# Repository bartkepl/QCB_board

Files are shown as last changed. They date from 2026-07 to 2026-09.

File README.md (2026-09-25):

# QCB (Quad Card Backplane)

Quad Card Backplane for 3U eurocards. Splits USB 2.0 and 10/100M Ethernet (plus RS485 and an ID EEPROM) out to 4 eurocards.

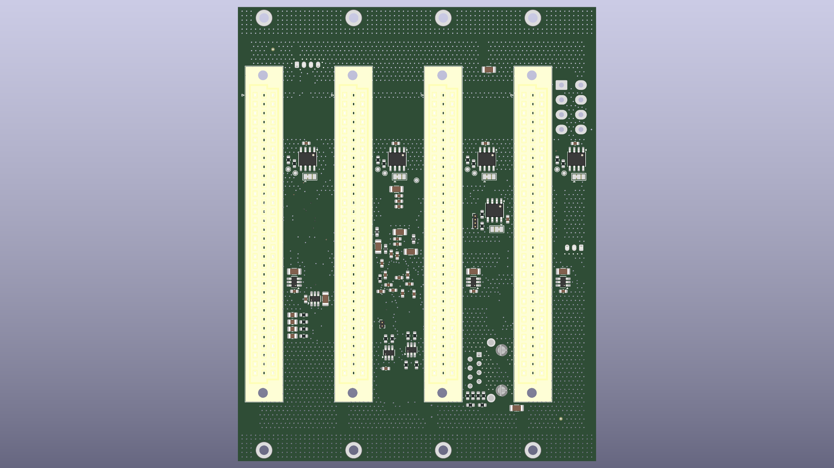
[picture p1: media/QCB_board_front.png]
Quad Card Backplane board


<p align="center">
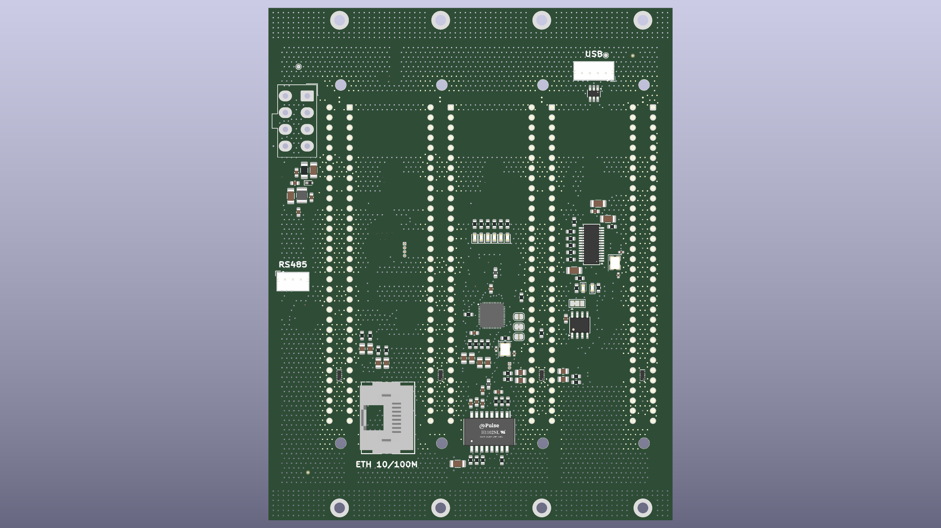
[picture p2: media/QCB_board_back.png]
QCB board back
  
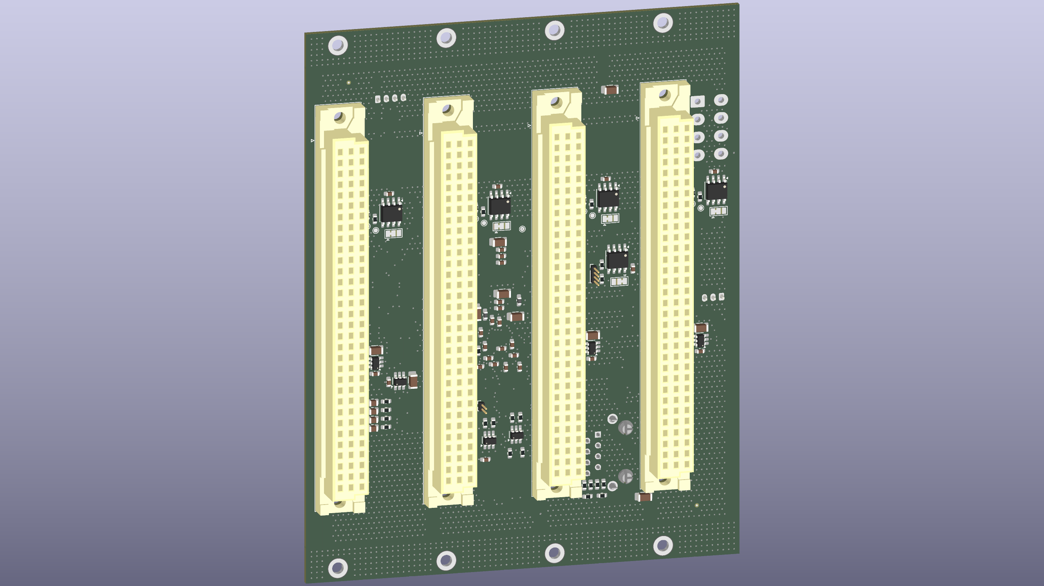
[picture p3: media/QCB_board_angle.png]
QCB board angle
  
</p>

---

## Status: ready for prototype order

- Schematic and PCB routing are done (rev 0.1), production files generated.
- A full design review (schematic + PCB + EMC + SPICE) was completed on 2026-08-03 and re-checked since; see [Documentation](#documentation) below.
- Fiducials added (2 per side, hand assembly), Y2 load caps C41/C42 now included in the BOM, datasheets for IP175G, FE1.1s and UT8413A in [doc/datasheet/](doc/datasheet/).

Production outputs: [schematic PDF](prod/sch/QCB_board.pdf) · [PCB PDF](prod/pcb/QCB_board.pdf) · [interactive BOM](prod/ibom/QCB_board_ibom.html) · [gerbers](prod/QCB_board.zip)

---

## Architecture

The board is a backplane hub card built around two switching ICs, fanned out to 4 identical eurocard channels:

- **U1 (FE1.1s)** — 4-port USB 2.0 Hi-Speed hub, one port per channel.
- **IC1 (IP175G)** — 5-port 10/100 Ethernet switch. One port is broken out to an RJ45 (J3) via magnetics (H1102NL); the other 4 go to the channels.
- **4× channel (`con1.kicad_sch`, reused as CON1–CON4)** — each with its own USB D+/D-, Ethernet TX/RX pairs, RS485±, ESD protection, and an identification EEPROM (M24C02) on its own I2C bus.
- **`pwr.kicad_sch`** — power input (Molex Mini-Fit connector J6), polyfuse, ferrite bead, ESD protection. No on-board regulator — +3.3V/+5V/+12V are supplied by the backplane.
- Channels land on 4 backplane connectors (DIN41612 2×32, J7–J10).

4-layer PCB (F.Cu / In1.Cu / In2.Cu / B.Cu), 101.6 × 128.7 mm.

## Features

- 10/100 Ethernet switch with an external RJ45 port
- USB 2.0 Hi-Speed 4-port hub
- Per-channel RS485 and identification EEPROM
- 4× 3U 6TE eurocard, IEEE 1101.1-1998 format (128 × 30.1 mm)
- Powered entirely from the backplane (no on-board regulator)

## Repository structure

```
pcb/        KiCad project (schematic, PCB, jobsets, 3D packages, datasheets cache)
doc/        Design review report, TODO list and component datasheets (tracked, human-readable)
media/      Renders/photos used in this README
prod/       Generated production outputs (gerbers/zip, BOM, schematic & PCB PDFs)
analysis/   Raw output of automated design-review tooling (gitignored, regenerable)
```

## Documentation

- [doc/DESIGN_REVIEW_2026-08-03.md](doc/DESIGN_REVIEW_2026-08-03.md) — full schematic/PCB/EMC/SPICE design review
- [doc/TODO.md](doc/TODO.md) — outstanding items before the board can be ordered

## License and Contribution

[MIT License](/LICENSE)

Open to contributions in both software and hardware!

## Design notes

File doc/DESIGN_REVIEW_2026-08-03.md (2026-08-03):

# Design Review — QuadCardBackplane_board (QCB), rev 0.1

Data przeglądu: 2026-08-03
Zakres: `pcb/QCB_board.kicad_sch` (+ arkusze `con1`, `eth_switch`, `usb_switch`, `pwr`) oraz `pcb/QCB_board.kicad_pcb`
Narzędzia: kicad-happy `kicad` (schematic/pcb/cross-analysis), `emc`, `spice` (ngspice), `analyze_thermal`, natywny `kicad-cli sch erc` / `kicad-cli pcb drc` (KiCad 10.0.4)

---

## 1. Co to za płytka

4-warstwowa karta backplane (F.Cu / In1.Cu / In2.Cu / B.Cu, grubość 1.586 mm), 101.6 × 128.7 mm, 216 komponentów. Funkcjonalnie:

- **U1 (FE1.1s)** — 4-portowy hub USB 2.0 Hi-Speed (480 Mb/s), rozprowadza D+/D− do 4 kanałów backplane (CON1–CON4).
- **IC1 (IP175G)** — 5-portowy switch Ethernet 10/100. Port 5 wyprowadzony na złącze RJ45 (J3, magnetyka H1102NL), porty 1–4 idą do kanałów backplane.
- **4× kanał (con1.kicad_sch reużyty jako CON1…CON4)** — każdy z własną parą USB D+/D−, parą Ethernet (CON_TX±/CON_RX±), RS485±, EEPROM identyfikacyjnym M24C02 na wspólnej magistrali I2C, ESD (USBLC6-2SC6, UT8413A) — wyprowadzone na złącza backplane DIN41612 2×32 (J7/J8/J9/J10).
- **pwr.kicad_sch** — wejście zasilania (złącze Molex Mini-Fit J6), bezpiecznik polimerowy F1, ferryt/dławik L1, ESD (D10). **Brak regulatora napięcia na płycie** — +3.3 V (i pozostałe szyny) pochodzą z backplane'u.

Zgodność schematyk↔PCB: **216 komponentów w schemacie = 216 footprintów na PCB** (dokładna zgodność). Liczba sieci: 237 (schematic) vs 263 (PCB) — różnica wynika z metodyki liczenia (PCB dolicza `unconnected-(...)` na niewykorzystanych pinach złączy DIN41612), nie jest błędem.

## 2. Co zostało uruchomione / czego brakowało

| Krok | Status |
|---|---|
| `analyze_schematic.py` | ✅ |
| `analyze_pcb.py --full --proximity` | ✅ |
| `cross_analysis.py` | ✅ (33 findings) |
| `analyze_emc.py` | ✅ (115 findings, 9 kategorii) |
| `kicad-cli sch erc` / `pcb drc` (natywny silnik KiCad 10.0.4) | ✅ — uruchomiony dodatkowo, poza standardowym workflow skilla, bo `D:\KiCad\10.0\bin\kicad-cli.exe` był dostępny |
| SPICE (ngspice) | ✅ — ngspice nie był w PATH, znaleziony pod `D:\Spice64\bin\ngspice.exe` (podałeś ścieżkę), użyty przez `NGSPICE_PATH`. 22 symulacje, 21 pass / 1 warn |
| Thermal | ✅ — 0 findings (na płycie nie ma zidentyfikowanych komponentów mocy typu regulator/driver z istotną dyssypacją — spójne z brakiem regulatora na tej karcie) |
| Sync datasheetów (DigiKey) | ❌ brak `DIGIKEY_CLIENT_ID`/`SECRET` w środowisku |
| Sync datasheetów (LCSC, bez klucza) | ⚠️ częściowy — tylko **1/10** komponentów z MPN miało pobieralny datasheet (H1102NL). Reszta (kondensatory GRM…, IP175G, USBLC6-2SC6 itd.) nie została znaleziona w LCSC/alt. źródłach automatycznie |
| Weryfikacja krytycznych pinów wobec prawdziwego datasheetu | ✅ ręcznie via WebSearch/WebFetch dla FE1.1s (Terminus Technology, Rev 1.0) — patrz sekcja 4 |
| Lifecycle audit (obsolescence) | ⛔ nie uruchomiony — pokrycie MPN w BOM to tylko 33% (13/39 unikalnych linii), audyt miałby sens dopiero po uzupełnieniu MPN |
| Gerber analyzer | ⛔ nie uruchomiony — w projekcie nie ma jeszcze wyeksportowanych gerberów |

**Uwaga o poziomie zaufania**: przy MPN pokryciu 33% i praktycznie zerowym pokryciu datasheetami, większość poniższych ustaleń to **weryfikacja spójności** (schemat ↔ PCB ↔ symbol biblioteczny), nie pełna weryfikacja wobec danych producenta — poza miejscami, gdzie jawnie cytuję konkretny datasheet (FE1.1s).

---

## 3. NAJWAŻNIEJSZE — realne błędy potwierdzone na surowych danych

### 3.1 ~~🔴 Kolizja adresów I2C~~ — WYCOFANE (2026-08-04)

> **Korekta**: to nie jest błąd. Autor potwierdził, że U6/U8/U10/U12 siedzą na 4 (docelowo 5) fizycznie **odrębnych** magistralach I2C — po jednej na każdy wpinany moduł identyfikacyjny backplane'u — a nie na jednej wspólnej. Poniższa analiza opierała się na grupowaniu przez detektor `PR-001`, który dopasowuje komponenty po **lokalnej** nazwie etykiety (`SCL`/`SDA`) i nie uwzględnia prefiksu instancji arkusza. Na PCB te same nazwy lokalne występują jako w pełni odrębne sieci (`/CON1/SCL`, `/CON2/SCL`, ...) — to sprawdzenie zrobiłem już po fakcie, nie przed nazwaniem tego "potwierdzonym błędem" w oryginalnym przeglądzie. Wniosek poniżej pozostawiony dla śladu, ale nieaktualny.

<details>
<summary>Oryginalna (błędna) analiza — rozwiń</summary>

#### Kolizja adresów I2C — 4× M24C02 na wspólnej magistrali z identycznym adresem (NIEAKTUALNE)

**Potwierdzone bezpośrednio w pinach**, nie tylko heurystyką: U6, U8, U10, U12 (po jednym EEPROM-ie M24C02-WMN na każdy kanał CON1–CON4) wiszą na **wspólnej** magistrali SCL/SDA (widoczne na złączach J7–J10, sygnały `/CONx/SCL`, `/CONx/SDA` idą wspólnie), a każdy z nich ma identyczne podłączenie pinów adresowych:

```
U6:  E0=GND  E1=+3.3V  E2=GND
U8:  E0=GND  E1=+3.3V  E2=GND
U10: E0=GND  E1=+3.3V  E2=GND
U12: E0=GND  E1=+3.3V  E2=GND
```

Wszystkie cztery odpowiadają pod tym samym adresem 7-bit I2C (1010 E2E1E0 = 1010010). Master nigdy nie odróżni EEPROM-u kanału 1 od kanału 3 — kolizja na SDA, nieprzewidywalne odczyty.

**Przyczyna źródłowa**: `con1.kicad_sch` jest reużywany 4× jako CON1…CON4 bez zmiany strapowania adresu przy każdej instancji.

**Rekomendacja**: nadać każdemu kanałowi unikalny adres (np. 000/001/010/011 przez E2E1E0), albo rozdzielić na 4 oddzielne magistrale/mux I2C, jeśli identyfikacja per-kanał ma sens niezależnie.

*(koniec nieaktualnej analizy — patrz korekta powyżej)*

</details>

### 3.2 🟠 Struktura warstw PCB — brak ciągłej płaszczyzny odniesienia na całej płycie

> **Aktualizacja (2026-08-04)**: zaakceptowane jako świadomy kompromis projektowy, nie błąd do poprawy. Przy 3 warstwach sygnałowych + 1 warstwie masy nie ma miejsca na dedykowaną, w pełni litą płaszczyznę bez ograniczenia routingu sygnałów — a zasilanie ma tu niższy priorytet niż sygnały. Analiza poniżej (ustalenia analizatorów) zostaje jako dokumentacja rzeczywistej struktury miedzi, ale nie wymaga akcji.

To najpoważniejsza, systemowa obserwacja z warstwy PCB, widoczna niezależnie w kilku detektorach jednocześnie (nie pojedynczy false-positive):

- **SU-001 (deterministic, x3, error)**: każda para sąsiednich warstw miedzi — F.Cu/In1.Cu, In1.Cu/In2.Cu, In2.Cu/B.Cu — jest sklasyfikowana jako "sygnał obok sygnału" bez litej płaszczyzny odniesienia pomiędzy nimi.
- **GP-001 (x65: 30 error + 35 warning)**: sieci sygnałowe mają 25–75% pokrycia płaszczyzną odniesienia na swojej długości routingu ("major"/"partial reference plane gap").
- **RP-001 (x22: 11 error + 11 warning)**: brak via stitching przy przejściach warstw.
- **RP-002 (x10, error, deterministic — z cross_analysis, liczone przez union-find na realnej miedzi)**: 10 różnicowych par Ethernetu (`1RX1_P/N`, `0RX0_P/N`, `4TX4_P/N`, `2RX2_P/N` itd.) fizycznie przecina szczeliny w miedzi wylanej siecią **+3.3V** na warstwach zewnętrznych F.Cu/B.Cu.
- **PS-002 (error)**: sieć +3.3V jest podzielona na **10 wysp** miedzi, z 23 sygnałami przecinającymi granice między nimi.

Sprawdziłem geometrię zalewów (`zones`): "+3.3V" na F.Cu/B.Cu to dziesiątki małych, lokalnych plamek miedzi (rzędu 0.3–1 mm²) wokół pinów zasilania, a nie jedna ciągła płaszczyzna — natomiast "Earth"/"GND" jest zalane głównie na warstwach wewnętrznych, ale też nie na całej powierzchni płyty. Efekt: prąd powrotny sygnałów szybkich (5-portowy switch Ethernet, USB Hi-Speed) często nie ma bliskiej, ciągłej ścieżki powrotnej — pętla powrotna się wydłuża, co podnosi promieniowanie EMI i pogarsza integralność sygnału.

**Rekomendacja**: przeznaczyć co najmniej jedną warstwę wewnętrzną (In1.Cu lub In2.Cu) na **litą, nieprzerywaną płaszczyznę GND** bez routingu sygnałowego po niej, i referencjonować do niej wszystkie różnicowe pary Ethernetu/USB oraz zegary. Doszyć via stitching wzdłuż krawędzi płaszczyzn +3.3V tam, gdzie sygnały muszą je przecinać.

### 3.3 🟡 Rozjazd długości par różnicowych USB (D+/D−) na kanałach backplane

> **Aktualizacja (2026-08-04)**: nie dotyczy — porty CON1–CON4 pracują jako USB 2.0 **Full-Speed** (12 Mb/s), nie Hi-Speed. Poniższa analiza zakładała Hi-Speed na podstawie samych możliwości hosta FE1.1s (który obsługuje Hi-Speed), a nie faktycznej prędkości negocjowanej na tych portach. Przy Full-Speed budżet skew jest rzędu nanosekund — rozjazd 5.7–7.4mm nie ma praktycznego znaczenia, zmiana niekonieczna.

FE1.1s (U1) to hub **Hi-Speed (480 Mb/s)** — potwierdzone w tabeli poboru prądu datasheetu (tryby "High-Speed 4x…"). Dla USB HS skew wewnątrz pary powinien być rzędu ułamka mm (budżet ~kilkuset ps, czyli ~1 mm przy typowej prędkości propagacji FR4). Zmierzone rozjazdy na PCB:

| Para | Δ długości | % |
|---|---|---|
| /CON1/D+ // D− | 5.7 mm | 72% |
| /CON2/D+ // D− | 7.4 mm | 56% |
| /CON3/D+ // D− | 5.7 mm | 72% |
| /CON4/D+ // D− | 5.7 mm | 72% |

To zdecydowanie za dużo dla Hi-Speed USB (kilka razy więcej niż typowy budżet skew). Jeśli te porty faktycznie mają negocjować Hi-Speed (a nic w schemacie nie ogranicza ich do Full-Speed), warto dostroić długości do <1 mm różnicy, albo świadomie potwierdzić, że kanały backplane mają działać tylko Full-Speed (12 Mb/s), gdzie ten skew nie ma znaczenia.

Dla porównania, pary Ethernetu (100 Mb/s, tolerancja dużo luźniejsza) mają rozjazdy 7–24% — mniej krytyczne, ale też warto wyrównać przy okazji poprawek layoutu.

### 3.4 🟠 BOM — 33% pokrycia MPN, blokada pre-fab

`SS-001`: tylko 13/39 unikalnych linii BOM (33.3%) ma numer katalogowy producenta — głównie brakuje MPN dla rezystorów, kondensatorów, diod, złączy J1/J2/J4/J5/J7-J10. Bez uzupełnienia MPN nie da się wygenerować BOM do zamówienia (JLCPCB/DigiKey/Mouser) ani zweryfikować dostępności/lifecycle. To task na skille `bom`/`digikey`/`lcsc`, jeśli chcesz iść w stronę zamówienia płytki.

### 3.5 🟡 Footprint D12–D15 (UT8413A) nie rozwiązuje się w bibliotece

Natywny `kicad-cli` (i ERC, i DRC) zgłasza dla D12, D13, D14, D15: footprint `Diodes_UDFN-10_1.0x2.5mm_P0.5mm` nie został znaleziony w bibliotece `Package_DFN_QFN`. Geometria na PCB istnieje (routing kompletny, liczba footprintów się zgadza), więc płytka fizycznie ma tam coś wylutowanego — ale referencja biblioteczna jest zerwana. Przed kolejną edycją/aktualizacją footprintów warto naprawić link (albo dodać brakujący footprint do lokalnej biblioteki projektu), inaczej KiCad nie będzie w stanie zaktualizować/zweryfikować tego footprintu przy re-imporcie.

Nie znalazłem datasheetu dla **UT8413A** (prawdopodobnie ESD/ochrona per-kanał, analogicznie do USBLC6-2SC6, w obudowie UDFN-10) — ani przez wyszukiwarkę, ani w LCSC/DigiKey bez kluczy API. **Jeśli masz link/PDF do UT8413A, chętnie zweryfikuję pinout wobec niego** — bez tego pinout tego komponentu jest tylko wewnętrznie spójny (schemat=PCB), niezweryfikowany wobec producenta.

---

## 4. Zweryfikowane FALSE POSITIVE (nie wymagają poprawki)

Zgodnie z metodologią przeglądu — poniższe zostały podniesione przez analizatory jako poważne, ale po weryfikacji wobec datasheetu / realnej topologii pinów okazują się prawidłowe:

**PP-001 — "U1 pin 28 (VD18) nie ma ścieżki DC do szyny zasilania"** (zgłoszone jako `error`).
Sprawdziłem prawdziwy datasheet FE1.1s (Terminus Technology, Rev. 1.0, tabela opisu pinów, SSOP-28):
- pin 28 `VD18` = "1.8V power input"
- pin 12 (w symbolu KiCad; pin 7 wg diagramu SSOP producenta) `VD18_O` = "1.8V power output from 3.3V→1.8V integrated regulator — a 10µF decoupling capacitor is required"

W schemacie oba piny (12 i 28) siedzą na **tej samej** sieci, razem z kondensatorem C5 = **10 µF** — dokładnie zgodnie z wymogiem datasheetu. To poprawny, zalecany obwód aplikacyjny; heurystyka BFS analizatora nie rozpoznała "power_out pin tego samego IC na tej samej sieci" jako ważnego źródła DC, bo sieć jest nienazwana (`__unnamed_109`). Nie wymaga zmian.

**DC-002 — "Brak kondensatora odsprzęgającego przy U14"** (zgłoszone jako `error`, EMC).
U14 to USBLC6-2SC6 — czysta macierz diod TVS (piny: I/O1, I/O2×2, GND, VBUS-jako-linia-chroniona). **Nie ma pinu zasilania** (brak VCC/power_in) — to komponent pasywny, odsprzęgnięcie fizycznie nie ma zastosowania. Heurystyka "każdy IC potrzebuje decoupling" fałszywie zadziałała na układ ochronny bez zasilania.

**9× "Input Power pin not driven" (natywny ERC) + 12× RS-001 "brak zadeklarowanego źródła"** (REG_OUT, VDD10, VDD33, DVCC, DVDD, +3.3V i in.).
Zweryfikowałem to na poziomie sieci — **nie są to pływające szyny**:
- `REG_OUT` (pin 41 `VREG_LDO` układu IC1/IP175G) zasila `VDD10` przez ferryt FB1 i `DVDD` przez ferryt FB2 — to wewnętrzny regulator IP175G analogicznie do przypadku VD18_O w FE1.1s. Ścieżka DC istnieje (rezystancja ferrytu DC ≈ 0), sam schematic-analyzer (bardziej wyrafinowany, uwzględnia ferryty w BFS) tego nie zgłasza jako PP-001 — zgadza się.
- `VDD33`/`DVCC` są zasilane z głównej szyny +3.3V przez ferryty FB3/FB4.
- Sam +3.3V nie ma nigdzie w projekcie pinu jawnie typowanego jako `power_out` — źródło to złącze zasilania J6 (Molex, `pwr.kicad_sch`), ale generyczny symbol złącza ma typy pinów `passive`, nie `power_out`.

**Przyczyna źródłowa (jedna, powtarzająca się)**: symbol IP175G pochodzi z SamacSys/Ultra Librarian i ma **wszystkie** piny stypowane jako `passive` zamiast `power_in`/`power_out` — ERC nie widzi wewnętrznego regulatora jako źródła. Do tego część szyn wewnętrznych (DVDD, VDD10, VDD33, DVCC, REG_OUT, PWR_OFF) jest nazwana przez generyczny symbol `power:VDD` (który w bibliotece KiCad ma typ pinu **input**, nie output) zamiast `PWR_FLAG`.

**Rekomendacja (kosmetyczna, nie funkcjonalna)**: dodać symbole `PWR_FLAG` w rzeczywistych punktach wejścia zasilania (pin J6 dla +3.3V/+5V/+12V na `pwr.kicad_sch`, ew. przy pinach regulatorów wewnętrznych IC1/U1) — wyciszy to i natywny ERC, i `RS-001`, bez zmiany realnego połączenia. Docelowo warto też poprawić typy pinów w niestandardowych symbolach SamacSys (IP175G, UT8413A, 100616-2 itd.) — obecnie "passive" wszędzie maskuje tę klasę błędów na przyszłość.

---

## 5. Pozostałe ustalenia — do przejrzenia, mniej pilne

| Obszar | Ustalenie | Rekomendacja |
|---|---|---|
| Zasilanie/SPICE | C1 (odsprzęgający) — SPICE (ngspice) pokazuje wysoką impedancję Z(100kHz)=1.59 kΩ, Z(1MHz)=159 Ω — pojedynczy kondensator, brak wsparcia przy wyższych częstotliwościach | Dodać drugi, mniejszy kondensator równolegle (np. 100nF + 10nF) |
| ESD | U4 (USBLC6-2SC6) — brak via GND w promieniu 3mm; U7/U9 — tylko 1 via GND (zalecane ≥2) | Dodać via GND blisko padów GND układów TVS — indukcyjność ścieżki do masy krytyczna przy ESD 8kV |
| ESD | U7/U9/U11 fizycznie oddalone od chronionych złączy J4/J5 | Przybliżyć układy TVS do złącza |
| Zegary | XIN/XOUT (U1), OSCI (IC1) routowane na warstwie zewnętrznej; OSCI blisko J5 | Rozważyć routing na warstwie wewnętrznej / stripline, odsunąć od złącza |
| Assembly | Brak fiducali na obu stronach (B.Cu ma komponenty fine-pitch/QFN, pad min. 0.20mm) | Dodać min. 3 fiducial markery na stronę |
| Test | Pokrycie punktami testowymi: 9/261 sieci (3%) | Rozważyć dodanie TP na kluczowych sieciach przed produkcją |
| DFM | Via annular ring 0.1mm < wymóg IPC Class 2 (0.125mm); płyta >100×100mm → wyższy próg cenowy JLCPCB (tier "advanced") | Zwiększyć annular ring, jeśli zamawiasz w klasie standard |
| Via-in-pad | 11× via w padzie bez tentowania (C21, C33, C49×2, C77, C80, C81, R2, TP11, TP2, Y1) | Zatentować/wypełnić lub potwierdzić, że fab obsługuje via-in-pad |
| Mechanika | J6 tylko 0.57mm od krawędzi płyty (zalecane ≥1.0mm) | Odsunąć lub potwierdzić z fabem |
| I2C | Poza kolizją adresów (3.1) — brak innych problemów na magistrali | — |
| Higiena ERC | "REG_IN" i "VDD33" to dwie etykiety tej samej sieci (ERC wybrał REG_IN) | Ujednolicić nazewnictwo dla czytelności |
| Złącza | J2 — zbyt mało pinów GND jak na wysokoprędkościowe sygnały; J3 (RJ45) pin 7 ma 25% pokrycia płaszczyzną odniesienia | Sprawdzić przydział GND na J2; doszyć miedź/via przy J3 pin 7 |

## 6. Weryfikacja SPICE

22 automatycznie wykryte podukłady (filtry RC, odsprzęganie zasilania), symulowane w ngspice-46:

- **21/22 pass** — obliczone częstotliwości odcięcia filtrów RC zgadzają się z SPICE z błędem 0.24% (rezystory/kondensatory mają prawidłowe wartości względem topologii).
- **1 warning** — C1 (opisane w sekcji 5, wysoka impedancja odsprzęgania powyżej ~1MHz).
- Sieci odsprzęgające C6–C33 (grupy kondensatorów przy IC1) mają Z_min rzędu 5–9 mΩ — bardzo dobre.

## 7. Nie wykonano / ograniczenia przeglądu

- **Lifecycle/obsolescence audit** — pominięty (za niskie pokrycie MPN, brak sensu bez uzupełnienia BOM).
- **Gerber analyzer** — pominięty (brak wyeksportowanych gerberów w projekcie).
- **Pełna weryfikacja datasheetowa** wszystkich 15 układów IC — tylko FE1.1s (U1) zweryfikowany wobec pełnego datasheetu producenta. IP175G (IC1), M24C02-WMN (U6/U8/U10/U12), USBLC6-2SC6 (U4/U7/U9/U11/U13/U14), UT8413A (D12-D15) — bez pobranych datasheetów, ustalenia dla nich to weryfikacja spójności schemat↔PCB↔symbol, nie wobec dokumentacji producenta.
- Jeśli chcesz, mogę spróbować ręcznie doszukać brakujące datasheety (IP175G, UT8413A, 100616-2) przez WebSearch/WebFetch tak jak zrobiłem dla FE1.1s — zajmie to dodatkowy czas, ale podniesie pewność ustaleń w sekcjach 3.1/3.5.

---

## 8. Priorytetowa lista działań

*(zaktualizowane 2026-08-04 po odpowiedziach autora — patrz [TODO.md](TODO.md) dla pełnego stanu)*

1. ~~I2C: rozdzielić adresy U6/U8/U10/U12~~ — **wycofane, false positive** (3.1).
2. ~~PCB stackup/GND: przeznaczyć warstwę wewnętrzną na litą płaszczyznę GND~~ — **zaakceptowany kompromis, nie wymaga zmiany** (3.2).
3. ~~USB D+/D−: wyrównać długości par~~ — **nie dotyczy, porty Full-Speed** (3.3).
4. **BOM**: uzupełnić MPN (skill `bom`) przed zamówieniem (3.4) — **nadal otwarte**.
5. **Footprint D12–D15**: naprawić referencję biblioteczną UT8413A + znaleźć datasheet (3.5) — **nadal otwarte**.
6. Fiducial markery (sekcja 5) — **nadal otwarte**. Reszta pozycji z sekcji 5 potwierdzona jako OK bez zmian — patrz [TODO.md](TODO.md).

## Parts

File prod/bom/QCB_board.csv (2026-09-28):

Oznaczenie | Wartość | Footprint | Opis | Liczba
C1,C15,C43 | 1nF/2kV | Capacitor_SMD:C_1206_3216Metric | 1206B102K202 | 3
C2,C9,C11,C12,C13,C14,C18,C19,C22,C23,C24,C25,C26,C27,C30,C33,C35,C36,C44,C45,C47,C48,C56,C57,C58,C60,C61,C62,C63,C64,C65,C67,C68,C69,C70,C71,C72,C74,C75,C76,C77,C78,C79,C81,C82,C83 | 100n | Capacitor_SMD:C_0603_1608Metric,Capacitor_SMD:C_0805_2012Metric | CGA4J3X7T2E104KAA,Unpolarized capacitor | 46
C3,C4,C5,C8,C17,C21,C29,C46,C49,C59,C66,C73,C80 | 10u | Capacitor_SMD:C_1206_3216Metric | CL31B106KBHNNNE | 13
C7,C16,C20,C28 | 1u | Capacitor_SMD:C_0603_1608Metric | CL10B105KA8NNNC | 4
C34 | 1n | Capacitor_SMD:C_0603_1608Metric | Unpolarized capacitor | 1
C37,C38 | 6.8n | Capacitor_SMD:C_0603_1608Metric | Unpolarized capacitor | 2
C39,C40 | 10n | Capacitor_SMD:C_0603_1608Metric | Unpolarized capacitor | 2
C41,C42 | 18p | Capacitor_SMD:C_0402_1005Metric | Unpolarized capacitor | 2
D1,D2,D3,D4,D5,D6,D7,D8 | Green | LED_SMD:LED_0603_1608Metric | Light emitting diode | 8
D10 | ESD5Z3.3T1G | Diode_SMD:D_SOD-523 | ESD Protection Diode, SOD-523 | 1
D12,D13,D14,D15 | UT8413A | Package_DFN_QFN:Diodes_UDFN-10_1x2.5mm_P0.5mm | TRANSIENT VOLTAGE SUPPRESSOR (TVS) ARRAY | 4
F1 | 1A | Fuse:Fuse_1206_3216Metric_Pad1.42x1.75mm_HandSolder | Resettable fuse, polymeric positive temperature coefficient | 1
FB1,FB2,FB3,FB4,FB5 | 100 @ 100MHz | Inductor_SMD:L_0603_1608Metric_Pad1.05x0.95mm_HandSolder | WLBD1608HCU101TL | 5
IC1 | IP175G | SamacSys_Parts:QFN40P600X600X90-49N-D | 5 Port 10/100 Ethernet Integrated Switch (85nm /Extreme Low Power, PWMT and AFT ) | 1
J3 | 100616-2 | SamacSys_Parts:1006162 | RJ45 Connector, Single Port, 1 x 1, Jack, Shielded, Cat 3, Standard - Latch Down, 8 Position, Standard Profile, Through Hole - Solder, Vertical | 1
J6 | 39-29-3086 | Connector_Molex:Molex_Mini-Fit_Jr_5566-08A_2x04_P4.20mm_Vertical | Mini-Fit Jr. Vertical Header, 4.20mm Pitch, Dual Row, 8 Circuits, without Snap-in Plastic Peg PCB Lock, Tin, Natural | 1
L1 | LQH32PN101MN0L | Inductor_SMD:L_1210_3225Metric | Inductor | 1
R1 | 0R | Resistor_SMD:R_0603_1608Metric | Resistor | 1
R3,R6 | 100k | Resistor_SMD:R_0603_1608Metric | Resistor | 2
R4,R5,R10,R21,R24,R25,R26,R27,R30 | 330 | Resistor_SMD:R_0603_1608Metric | Resistor | 9
R9 | 2.7k | Resistor_SMD:R_0603_1608Metric | Resistor | 1
R11,R12,R13,R14,R15,R16,R41,R42 | 49.9 | Resistor_SMD:R_0603_1608Metric | Resistor | 8
R17,R18,R19,R20,R28,R29,R31,R32,R37,R38,R39,R40,R47,R48,R49,R50,R51,R52,R53,R54 | 2.2 | Resistor_SMD:R_0603_1608Metric | Resistor | 20
R33 | 6.19k | Resistor_SMD:R_0603_1608Metric | Resistor | 1
R34,R35,R36 | 10k | Resistor_SMD:R_0603_1608Metric | Resistor | 3
R43 | 10 | Resistor_SMD:R_0603_1608Metric | Resistor | 1
R45,R46 | 82 | Resistor_SMD:R_0603_1608Metric | Resistor | 2
R55,R56 | 75 | Resistor_SMD:R_0603_1608Metric | Resistor | 2
R57,R58 | 150 | Resistor_SMD:R_0603_1608Metric | Resistor | 2
T1 | H1102NL | SamacSys_Parts:SOIC127P940X597-16N | PULSE ELECTRONICS - H1102NL - TRANSFORMER, 1:1, 1PORT, 100BASE-TX, SMT | 1
U1 | FE1.1s | Package_SO:SSOP-28_3.9x9.9mm_P0.635mm | USB 2.0 High Speed 4-Port Hub Controller, SSOP-28 | 1
U4,U5,U7,U9,U11,U13,U14 | USBLC6-2SC6 | Package_TO_SOT_SMD:SOT-23-6_Handsoldering | Very low capacitance ESD protection diode, 2 data-line, SOT-23-6 | 7
U6,U8,U10,U12 | M24C02-WMN | Package_SO:SOIC-8_3.9x4.9mm_P1.27mm | 2Kb (256x8) I2C Serial EEPROM, 2.5-5.5V, SOIC-8 | 4
Y1 | ABM8G-12.000MHZ-18 | Crystal:Crystal_SMD_Abracon_ABM8G-4Pin_3.2x2.5mm | Four pin crystal, GND on pins 2 and 4 | 1
Y2 | 3225-25M-SR | Crystal:Crystal_SMD_3225-4Pin_3.2x2.5mm | Four pin crystal, GND on pins 2 and 4 | 1

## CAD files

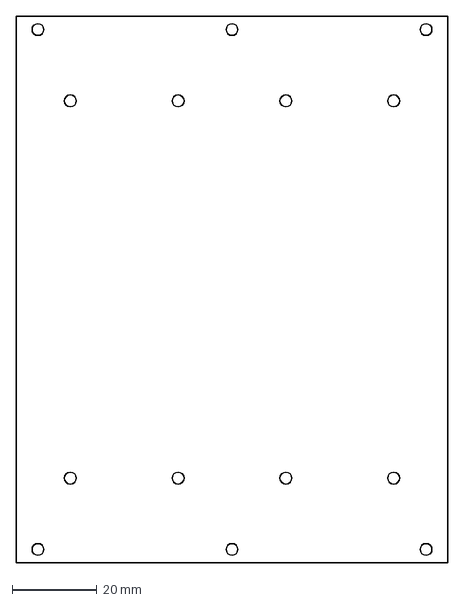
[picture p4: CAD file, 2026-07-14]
pcb/backplane/backplane.dxf
101.6 x 128.7 mm

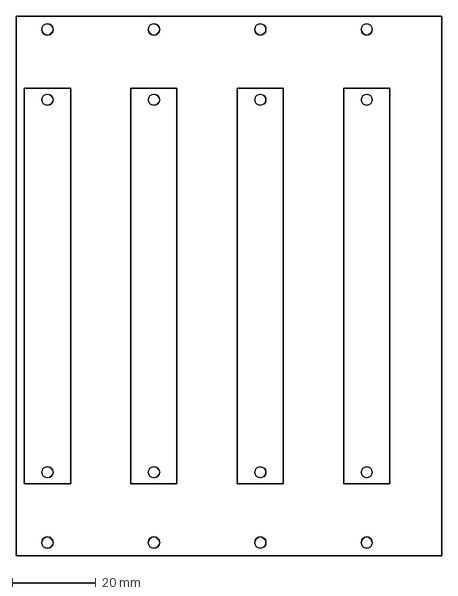
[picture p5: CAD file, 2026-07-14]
pcb/backplane/backplane2.dxf
101.6 x 128.7 mm

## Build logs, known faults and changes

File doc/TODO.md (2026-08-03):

# TODO — QuadCardBackplane_board (QCB)

Wygenerowane z pełnego design review (schematic + PCB) z 2026-08-03, zaktualizowane po odpowiedziach z 2026-08-04. Szczegóły i uzasadnienia: [DESIGN_REVIEW_2026-08-03.md](DESIGN_REVIEW_2026-08-03.md) (zawiera teraz też korekty tam, gdzie przegląd się mylił).

## 🔴 Krytyczne — funkcjonalne błędy

- [x] ~~I2C: kolizja adresów EEPROM~~ — **false positive, wycofane.** U6/U8/U10/U12 są na 4 (docelowo 5) fizycznie odrębnych magistralach I2C, po jednej na każdy wpinany moduł identyfikacyjny backplane'u — nie są ze sobą połączone. Mój wniosek o "wspólnej magistrali" wynikał z tego, że detektor `PR-001` grupuje komponenty po lokalnej nazwie etykiety (`SCL`/`SDA`) bez uwzględnienia prefiksu instancji arkusza — na PCB te same nazwy występują jako osobne sieci `/CON1/SCL`, `/CON2/SCL` itd., czego nie sprawdziłem krzyżowo przed nazwaniem tego "potwierdzonym błędem". Identyczne strapowanie E0/E1/E2 na każdym module nie jest problemem, bo każdy siedzi na swojej własnej magistrali.
- [x] ~~PCB: brak ciągłej płaszczyzny GND~~ — **zaakceptowane ryzyko, nie błąd.** Przy 3 warstwach sygnałowych + 1 masie nie ma miejsca na dedykowaną, w pełni litą płaszczyznę bez kompromisów w routingu; zasilanie ma tu niższy priorytet niż sygnały. Świadoma decyzja projektowa — zostawiam jak jest.
- [x] ~~USB D+/D− skew na CON1–CON4~~ — **nie dotyczy.** Kanały pracują jako USB 2.0 Full-Speed (12 Mb/s), nie Hi-Speed — przy tej prędkości budżet skew jest rzędu nanosekund, więc rozjazd 5.7–7.4mm nie ma praktycznego znaczenia. Mój wniosek zakładał Hi-Speed na podstawie samych możliwości hosta FE1.1s, nie faktycznej konfiguracji/wykorzystania portów.

## 🟠 Ważne — przed zamówieniem płytki

*(bez zmian — nadal otwarte)*

- [ ] **BOM: uzupełnić MPN** — tylko 33% (13/39) unikalnych linii BOM ma numer katalogowy. Brakuje głównie rezystorom, kondensatorom, diodom, złączom J1/J2/J4/J5/J7–J10. Użyć skilla `bom`/`digikey`/`lcsc` do uzupełnienia przed eksportem do zamówienia.
- [ ] **Footprint UT8413A (D12, D13, D14, D15)** — referencja biblioteczna `Diodes_UDFN-10_1.0x2.5mm_P0.5mm` w `Package_DFN_QFN` nie rozwiązuje się (błąd w natywnym ERC/DRC KiCad). Naprawić link biblioteczny lub dodać footprint do lokalnej biblioteki projektu.
- [ ] **Znaleźć/podać datasheet UT8413A** — nie znaleziony automatycznie (nie ma w LCSC bez klucza, brak trafień w wyszukiwarce). Bez niego pinout tego ESD/ochrony per-kanał jest tylko wewnętrznie spójny (schemat=PCB), niezweryfikowany wobec producenta.
- [ ] **Zdobyć klucze API DigiKey / Mouser / element14** (opcjonalnie), jeśli ma być pełny automatyczny sync datasheetów — obecnie tylko 1/10 komponentów z MPN ma pobrany datasheet (H1102NL).

## 🟡 Do poprawy — layout / EMC / DFM

- [x] ~~Drugi kondensator odsprzęgający równolegle do C1~~ — **sprawdzone, OK bez zmian.** (impedancja z SPICE zaakceptowana jako wystarczająca)
- [x] ~~Via GND przy TVS U4/U7/U9~~ — **sprawdzone, OK bez zmian.**
- [x] ~~Odległość TVS U7/U9/U11 od złączy J4/J5~~ — **sprawdzone, OK.** Zabezpieczenia są umyślnie jak najbliżej źródła zagrożenia (złącza) — zgodnie z dobrą praktyką ESD, nie wymaga zmiany.
- [x] ~~Routing zegarów (XIN/XOUT U1, OSCI IC1) na warstwie zewnętrznej~~ — **sprawdzone, OK bez zmian.**
- [ ] Dodać min. 3 fiducial markery na stronę (B.Cu ma komponenty fine-pitch/QFN — pad min. 0.20mm, brak fiducali utrudni pick-and-place). *(nadal otwarte)*
- [x] ~~Via annular ring 0.1mm poniżej IPC Class 2~~ — **sprawdzone, OK bez zmian** (akceptowany tier "advanced" w JLCPCB).
- [x] **Tentowanie/wypełnienie via-in-pad** (C21:2, C33:2, C49:2 ×2, C77:1, C80:2, C81:1, R2:2, TP11:1, TP2:1, Y1:2) — **wykonane.**
- [x] ~~Odległość J6 od krawędzi płyty (0.57mm)~~ — **sprawdzone, OK bez zmian.**
- [x] ~~Przydział pinów GND na J2~~ — **sprawdzone, OK bez zmian.**
- [x] ~~Miedź/via przy J3 (RJ45) pin 7~~ — **sprawdzone, OK bez zmian.**
- [x] ~~Punkty testowe (3% pokrycia sieci)~~ — **nie dotyczy.** Produkcja bez ICT/flying probe — wszystko ewentualnie testowane ręcznie, więc niskie pokrycie TP nie jest problemem.

## 🟢 Kosmetyka / higiena ERC (nie wpływa na działanie)

- [x] Dodać symbole `PWR_FLAG` w punktach wejścia zasilania (J6, regulator wewnętrzny IC1) — **zaznaczone jako zrobione.**
- [x] Ujednolicić nazwy sieci REG_IN/VDD33 — **zaznaczone jako zrobione.**
- [x] Zaktualizować symbole niezgodne z biblioteką (JP1–JP5, Y1, Y2) — **zaznaczone jako zrobione.**

## ⏭️ Do wykonania w kolejnym przeglądzie (gdy będzie więcej danych)

- [ ] Dociągnąć pełną weryfikację datasheetową dla IC1 (IP175G), M24C02-WMN, USBLC6-2SC6, UT8413A — obecnie zweryfikowany wobec pełnego datasheetu producenta jest tylko U1 (FE1.1s).

---

**Stan po tej turze**: sekcja krytyczna (🔴) w całości zamknięta — wszystkie trzy pozycje okazały się nieporozumieniami przeglądu, nie realnymi błędami. Sekcja 🟡 zamknięta poza fiducialami. Otwarte pozostają: fiducial markery, uzupełnienie BOM/MPN, i temat footprintu + datasheetu UT8413A (D12–D15) — to jedyne realnie nierozwiązane punkty przed zamówieniem płytki.

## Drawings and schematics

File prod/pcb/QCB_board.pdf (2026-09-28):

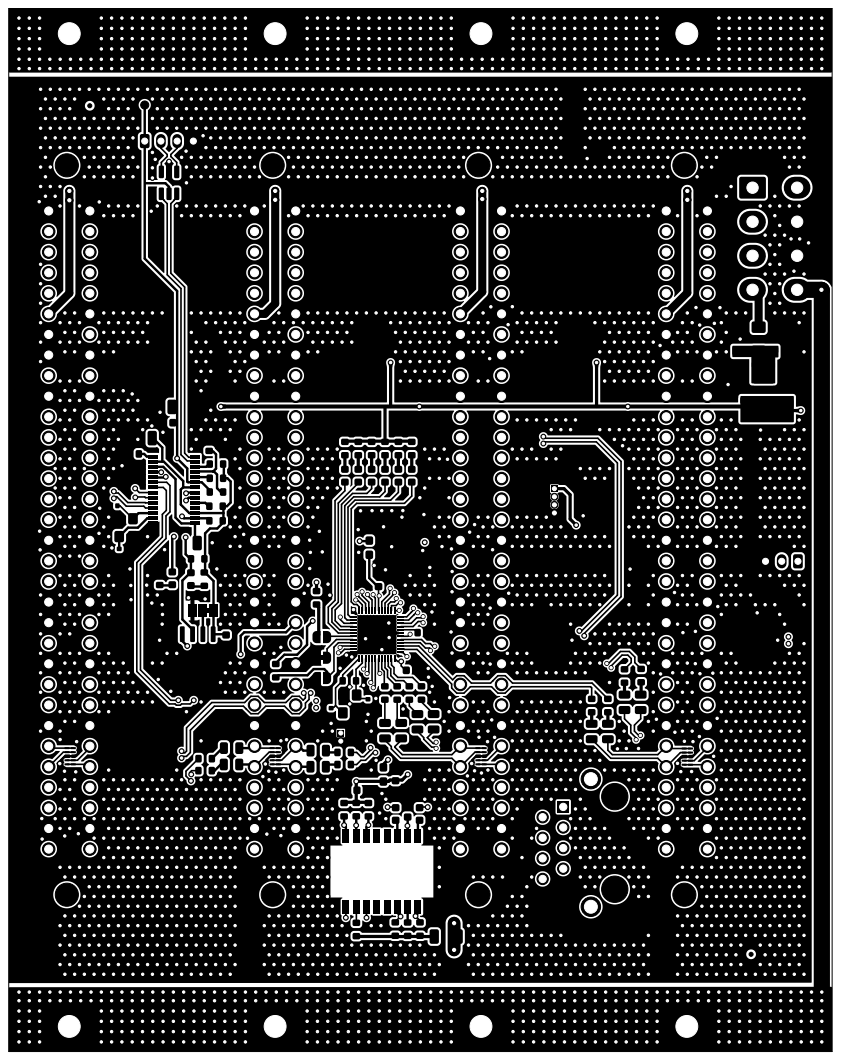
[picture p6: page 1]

Sheet:
File: QCB_board.kicad_pcb
Title: Standalone Connector Adapter board

Size: A4 | Rev: 0.3
KiCad E.D.A. 10.0.4 | Id: 1/6

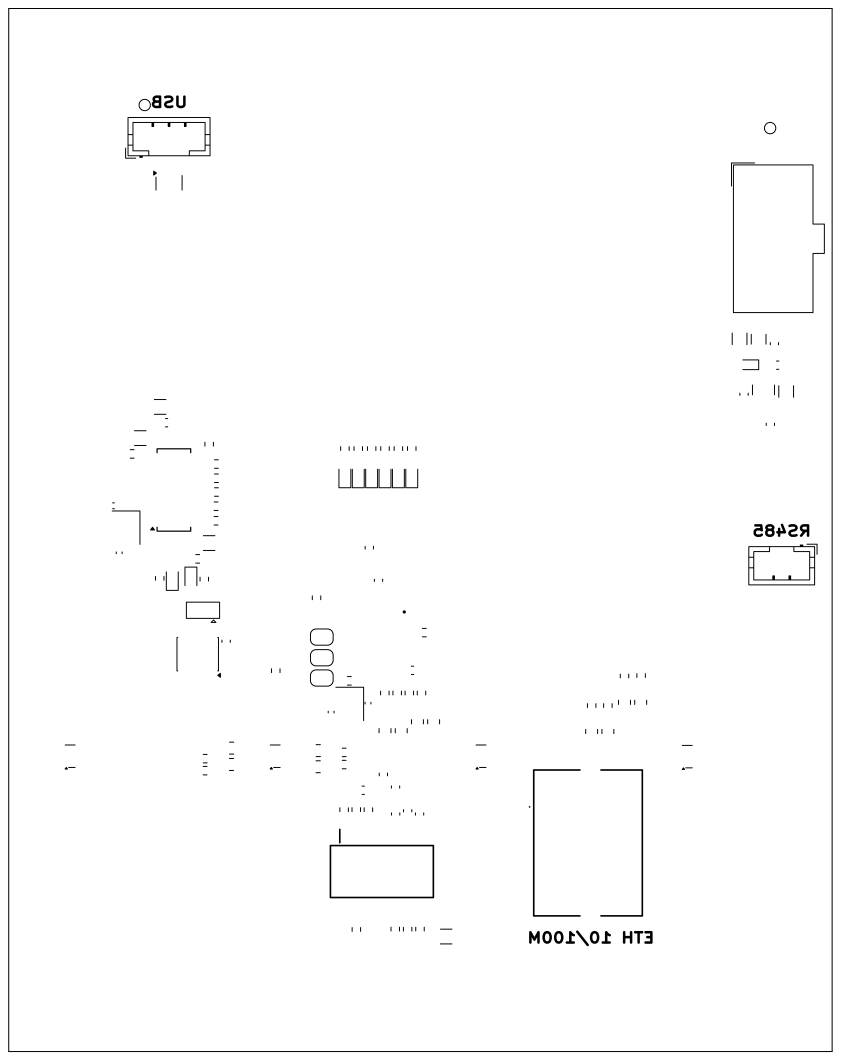
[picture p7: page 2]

Sheet:
File: QCB_board.kicad_pcb
Title: Standalone Connector Adapter board

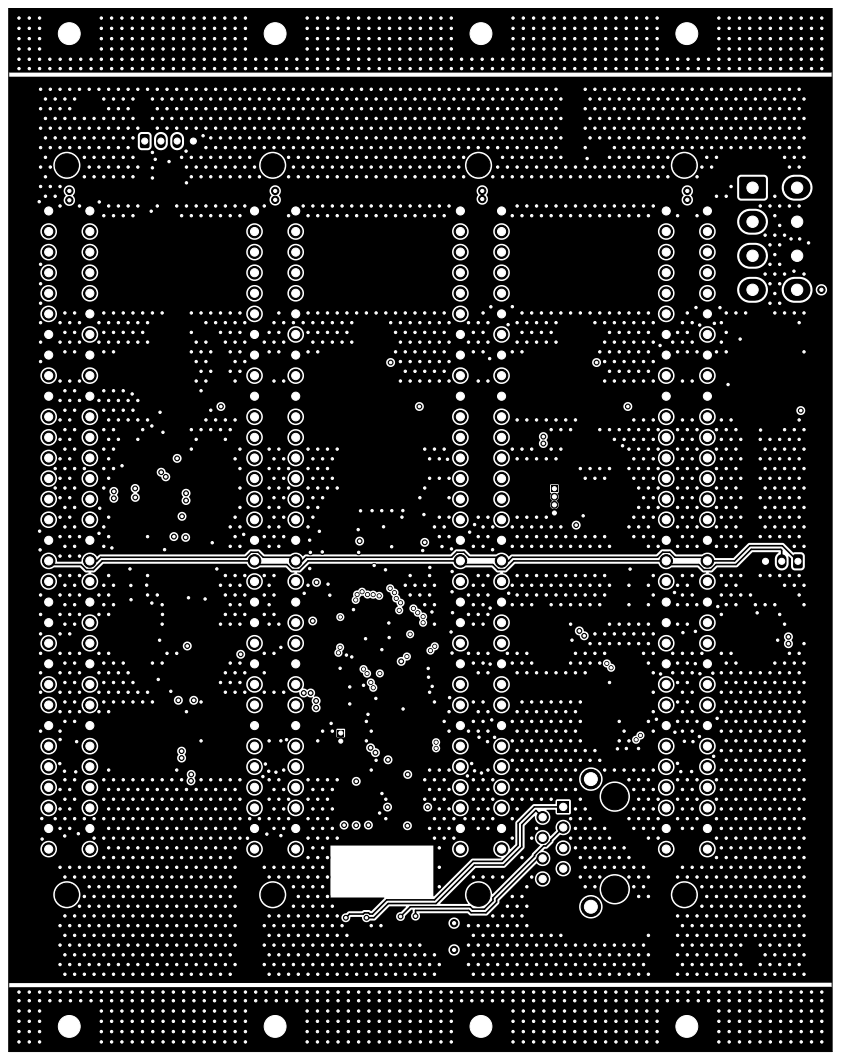
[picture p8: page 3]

Sheet:
File: QCB_board.kicad_pcb
Title: Standalone Connector Adapter board

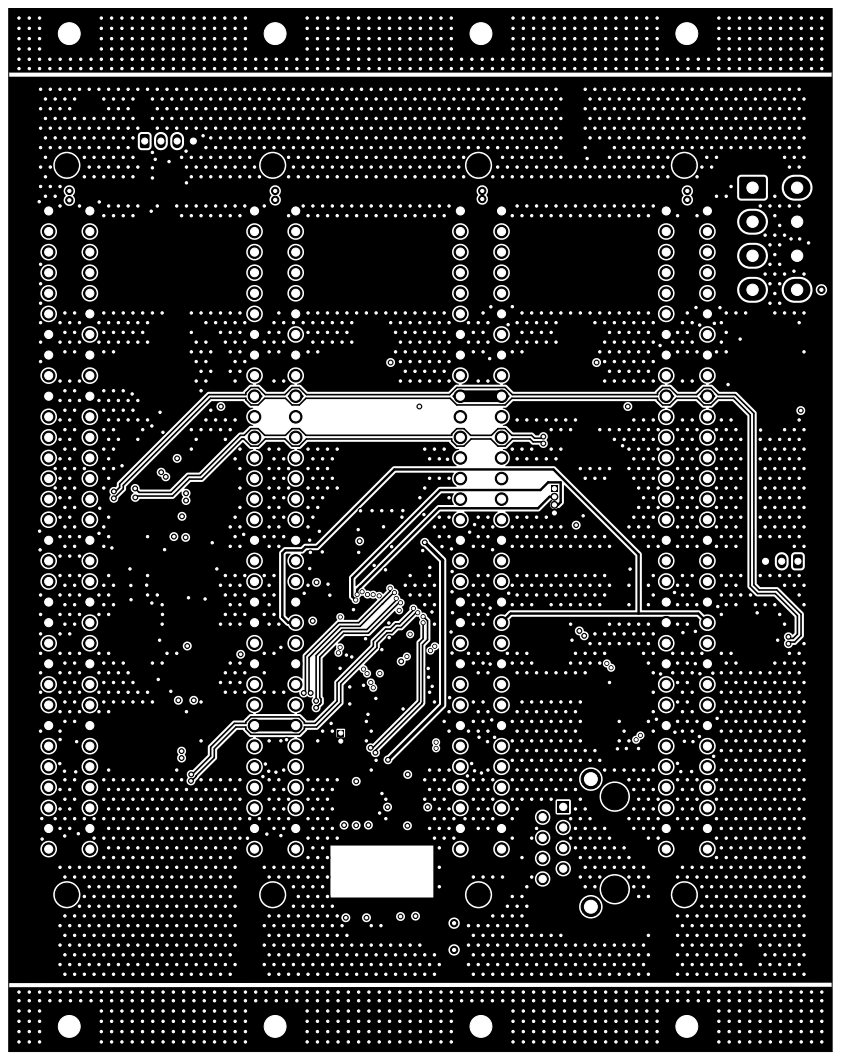
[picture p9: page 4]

Sheet:
File: QCB_board.kicad_pcb
Title: Standalone Connector Adapter board

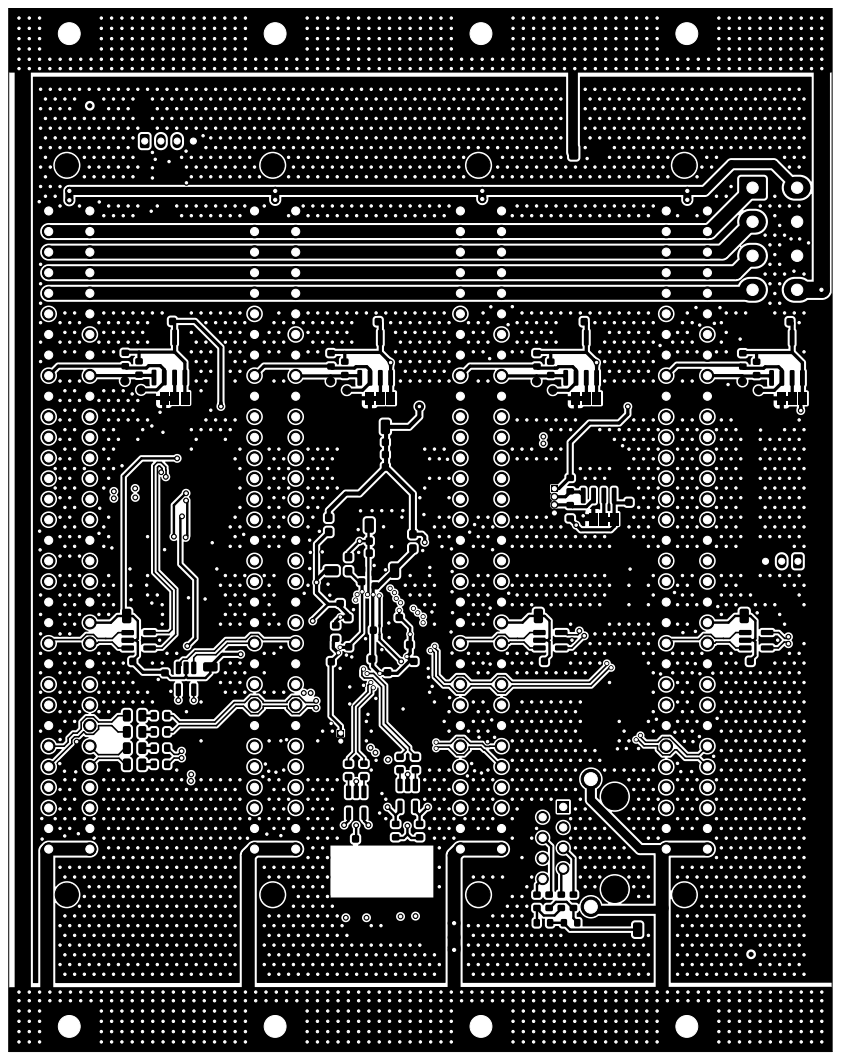
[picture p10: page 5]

Sheet:
File: QCB_board.kicad_pcb
Title: Standalone Connector Adapter board

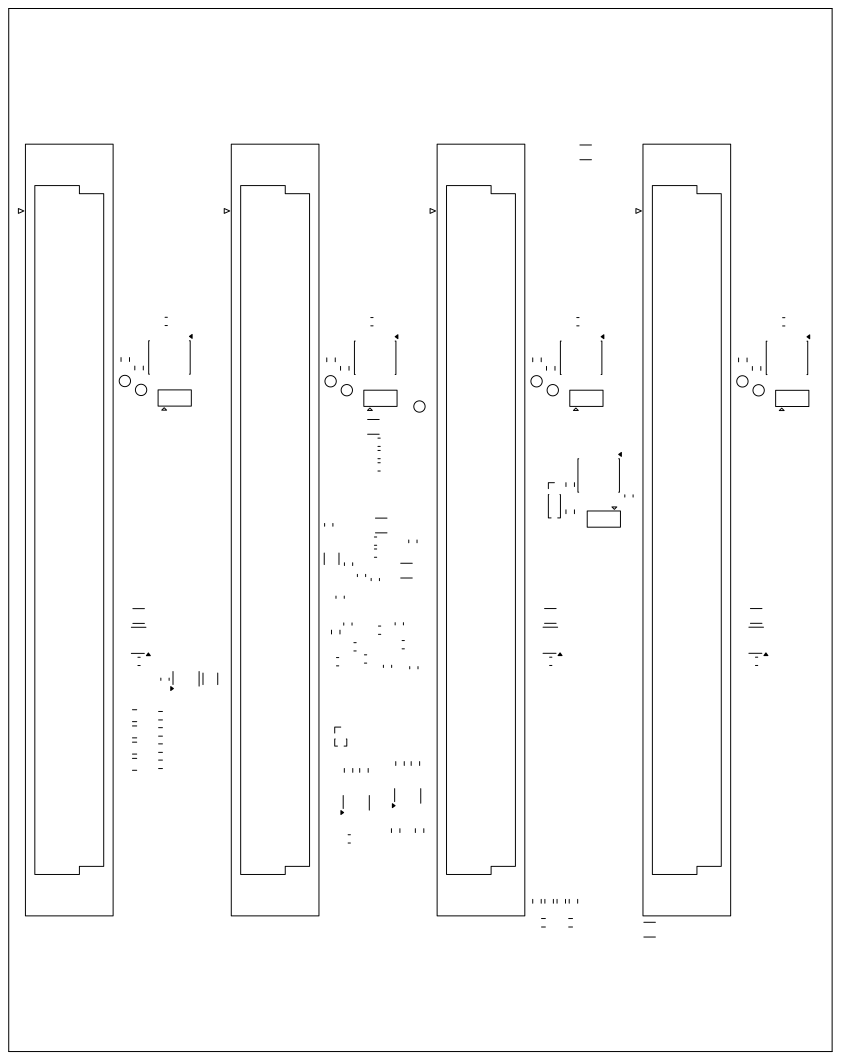
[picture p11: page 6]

Sheet:
File: QCB_board.kicad_pcb
Title: Standalone Connector Adapter board

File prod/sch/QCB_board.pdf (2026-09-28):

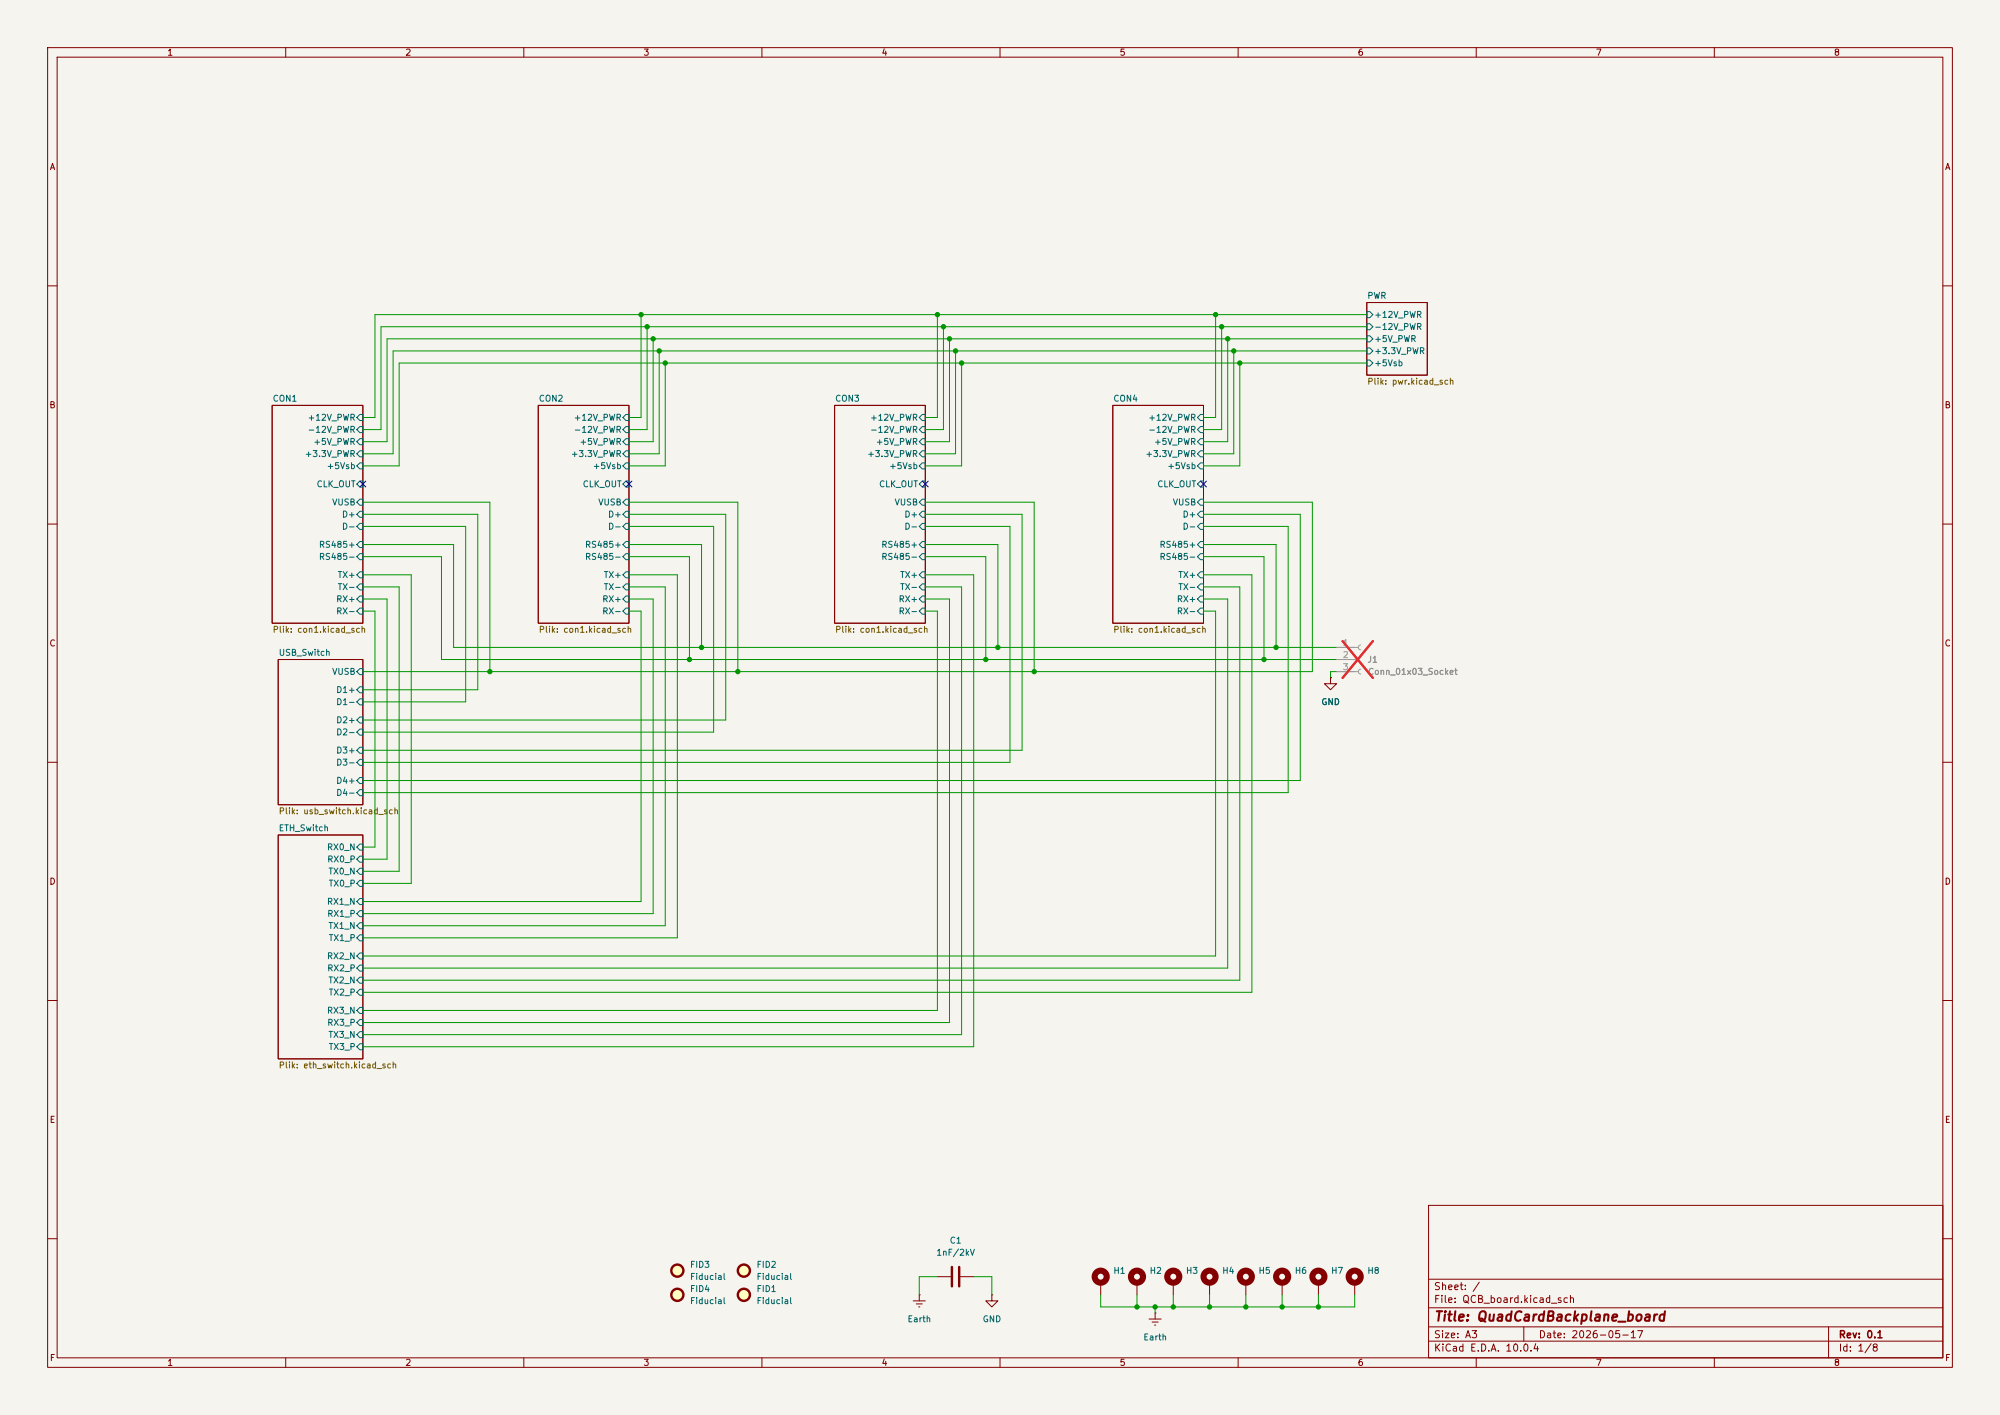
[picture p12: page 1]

Size: A3 | Rev: 0.1 | F Date: 2026-05-17
KiCad E.D.A. 10.0.4 | Id: 1/8

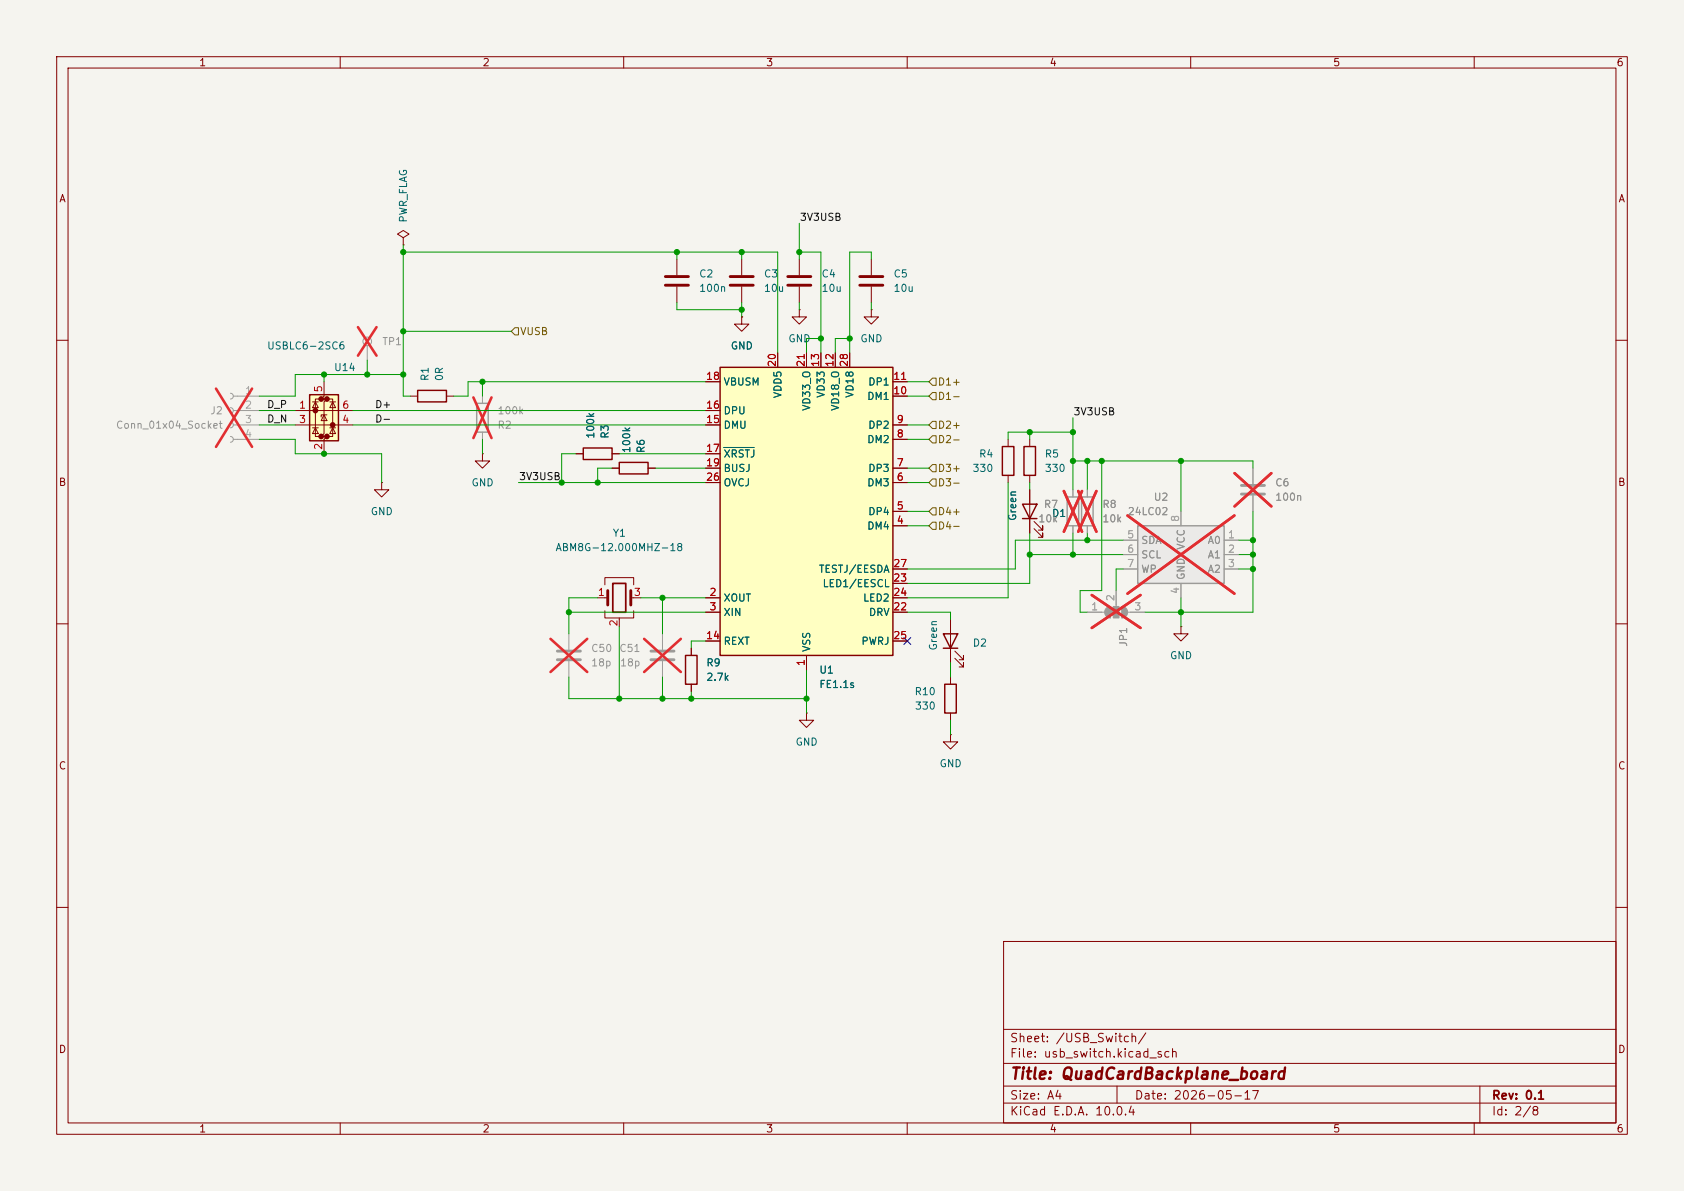
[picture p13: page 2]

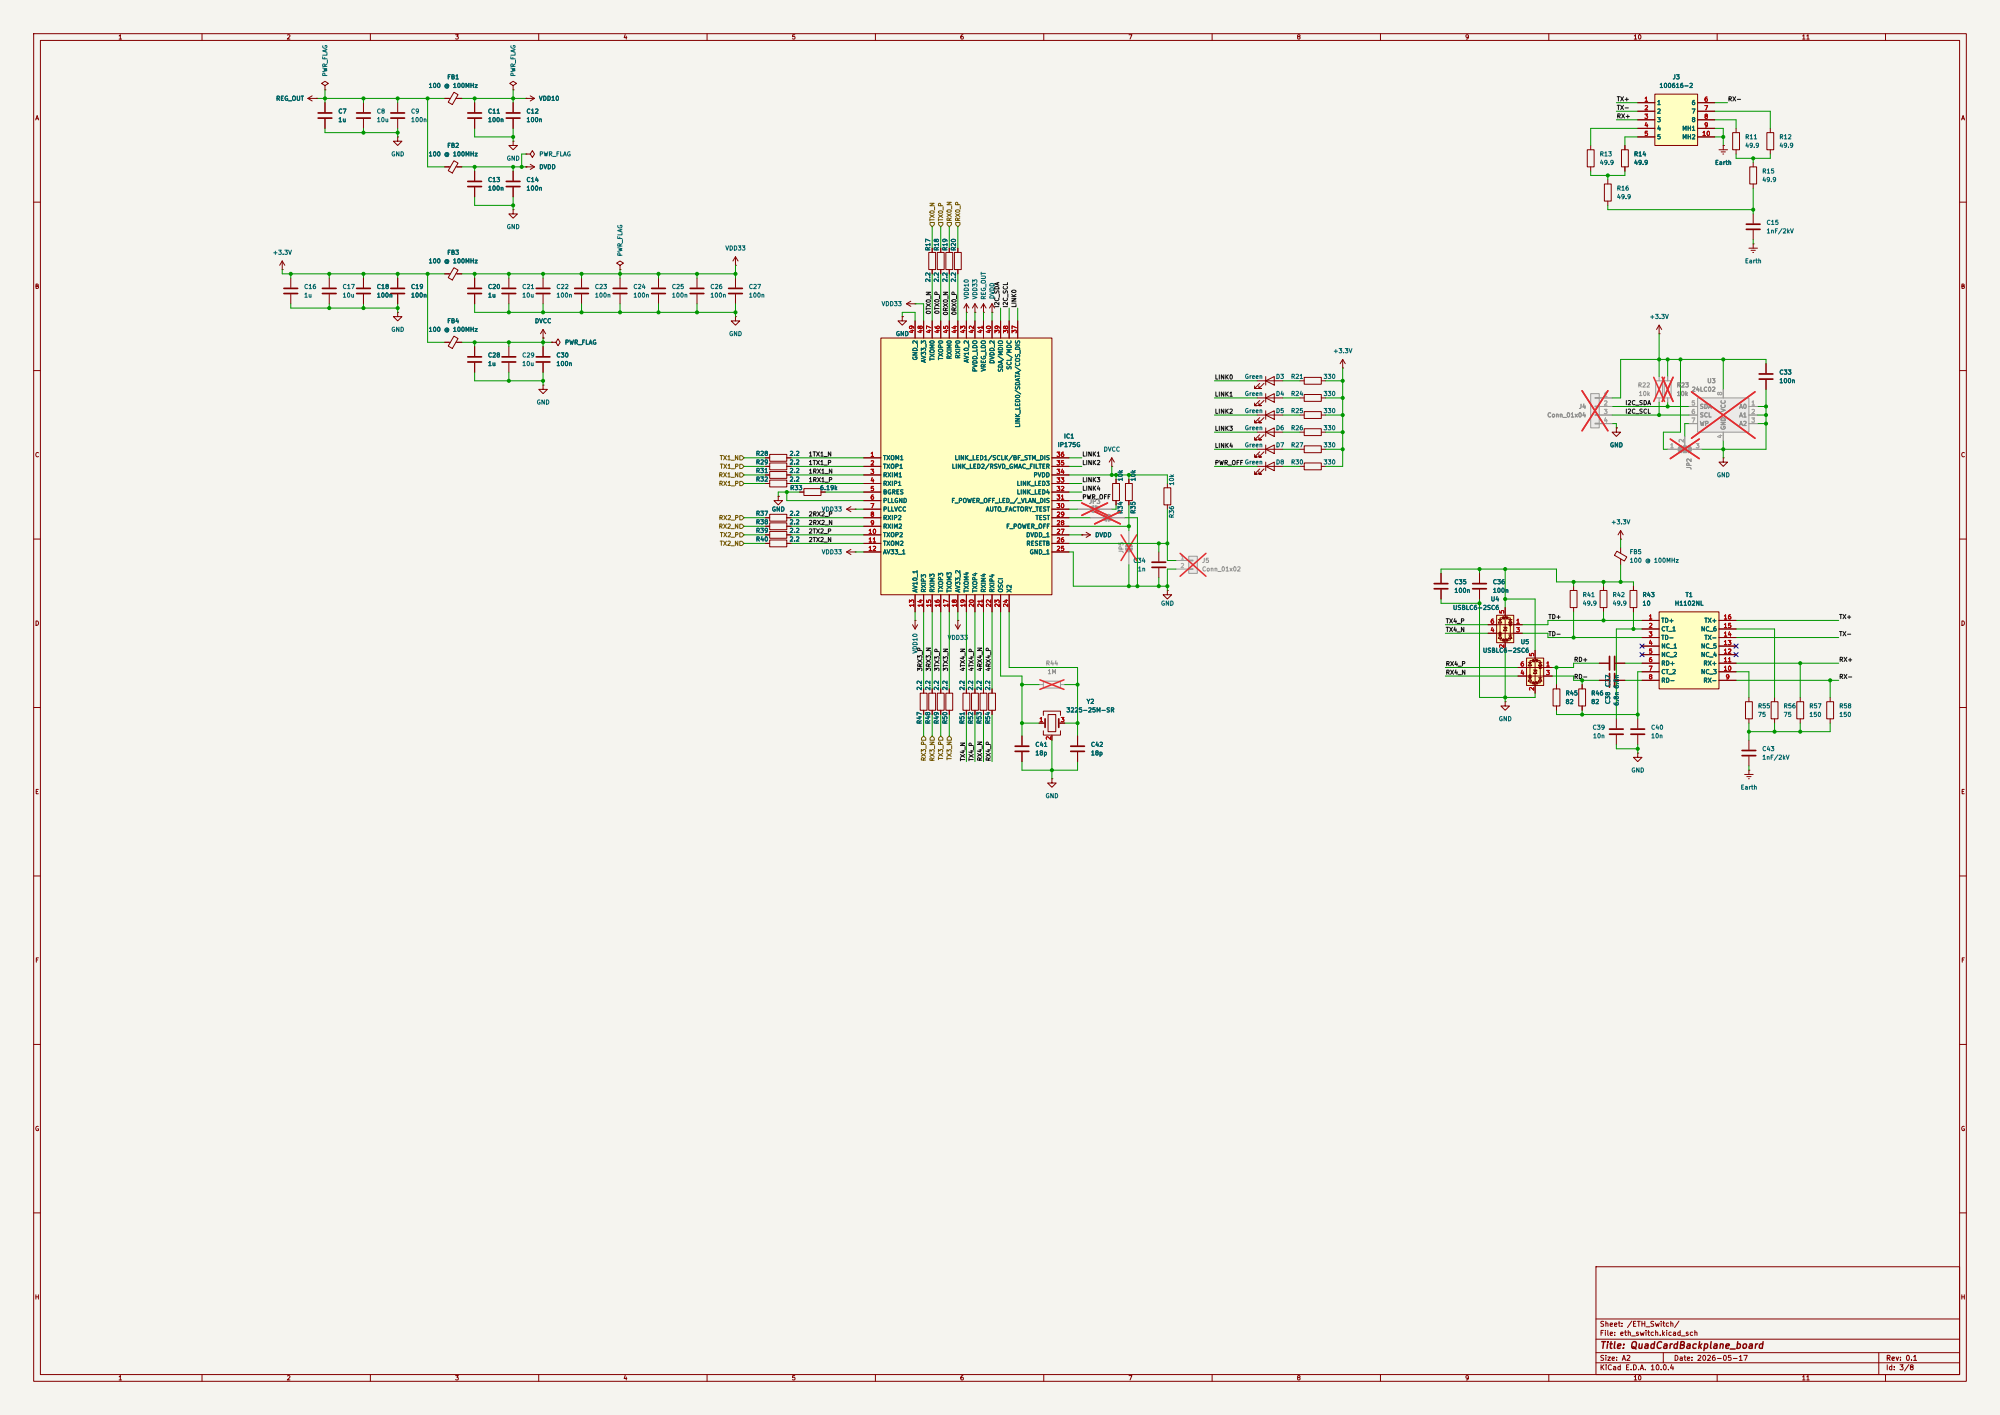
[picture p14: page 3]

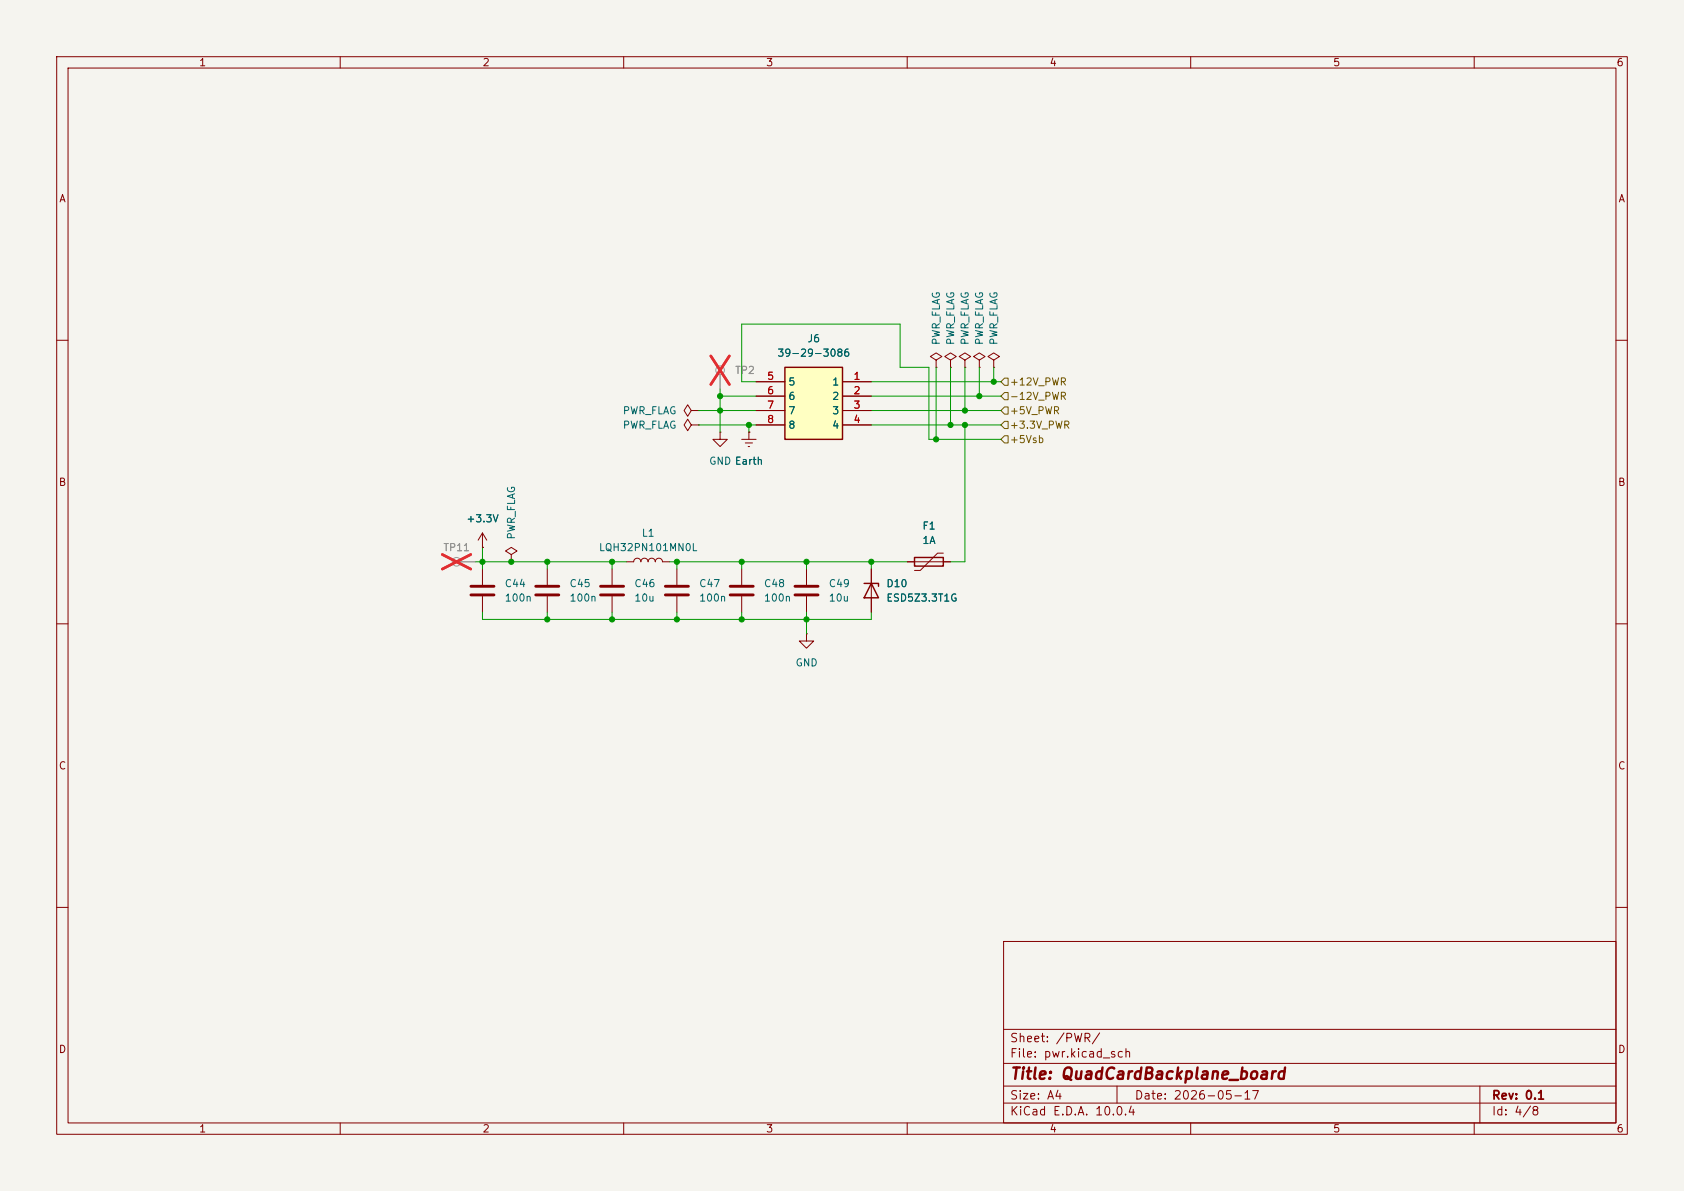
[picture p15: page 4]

2 2
3 3
4 4

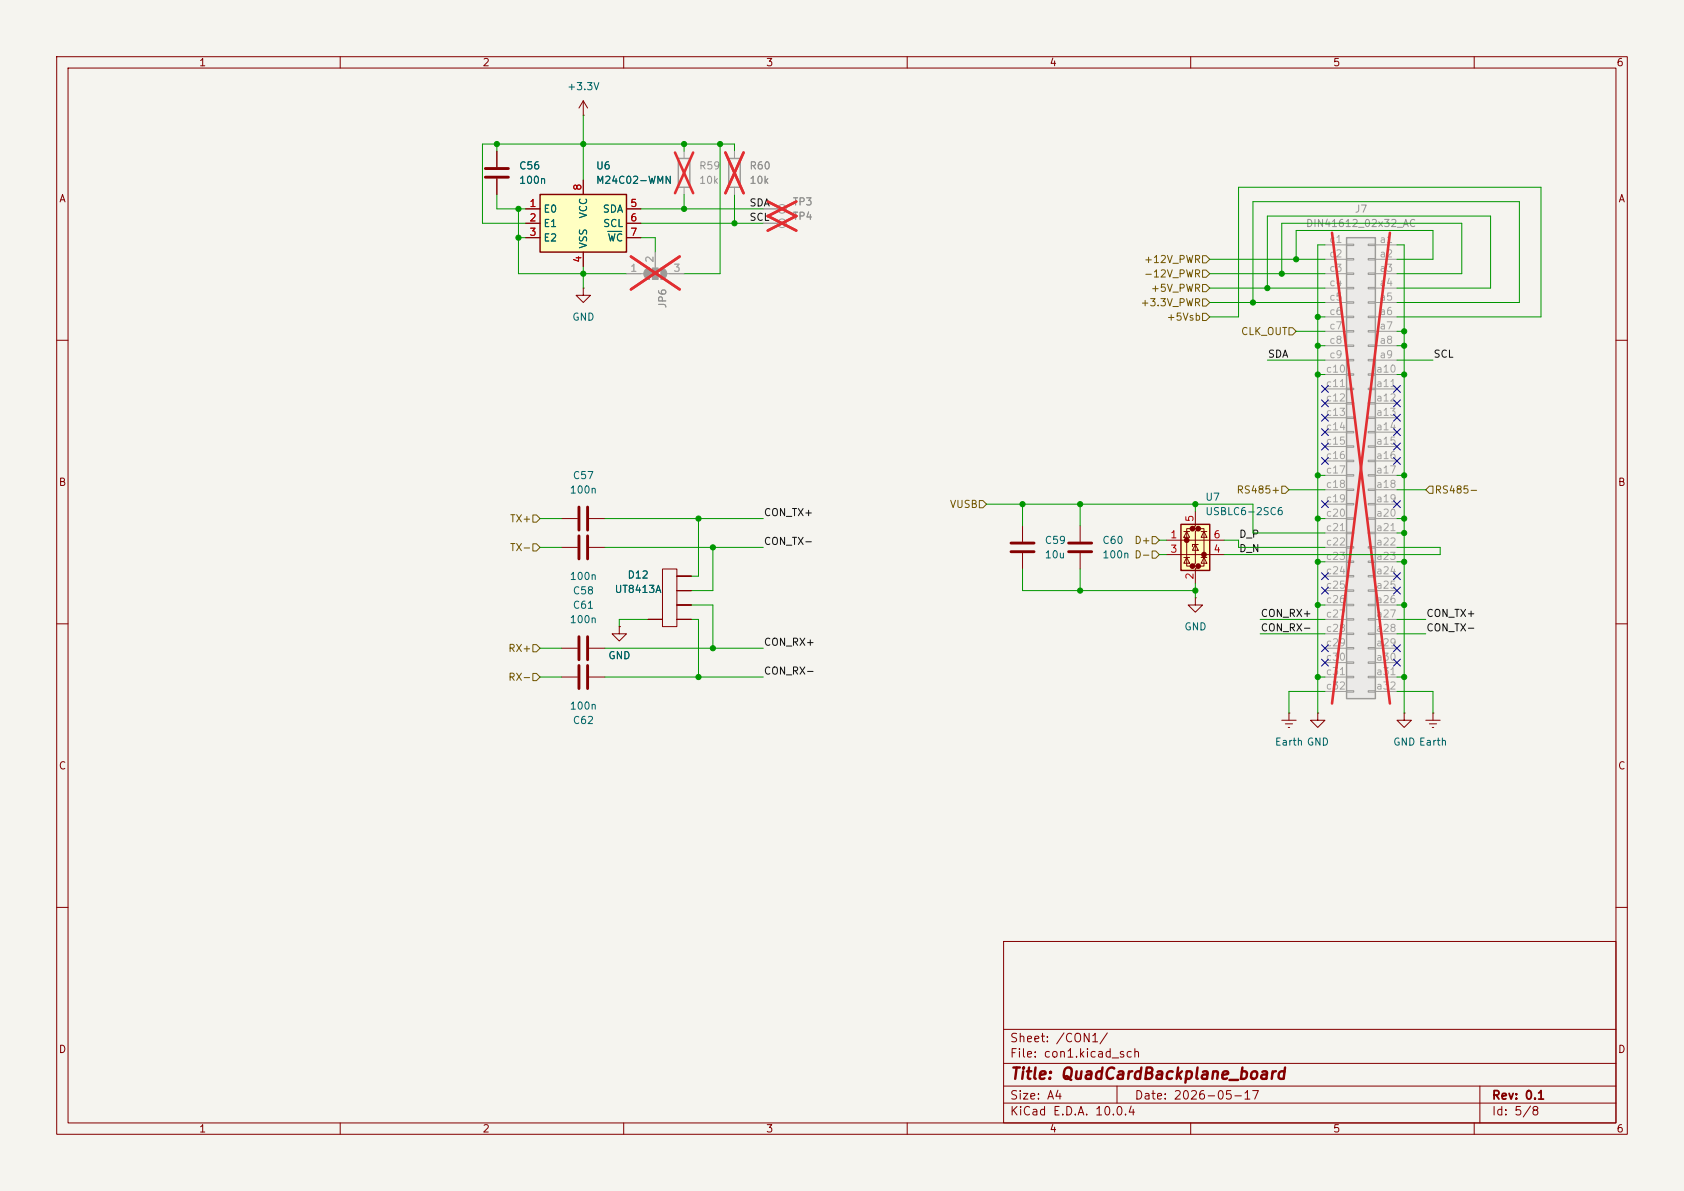
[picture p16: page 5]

CLK_OUT +5Vsb -12V_PWR +5V_PWR +12V_PWR | c4 | a4

c5 | a5
c6 c7 | a6

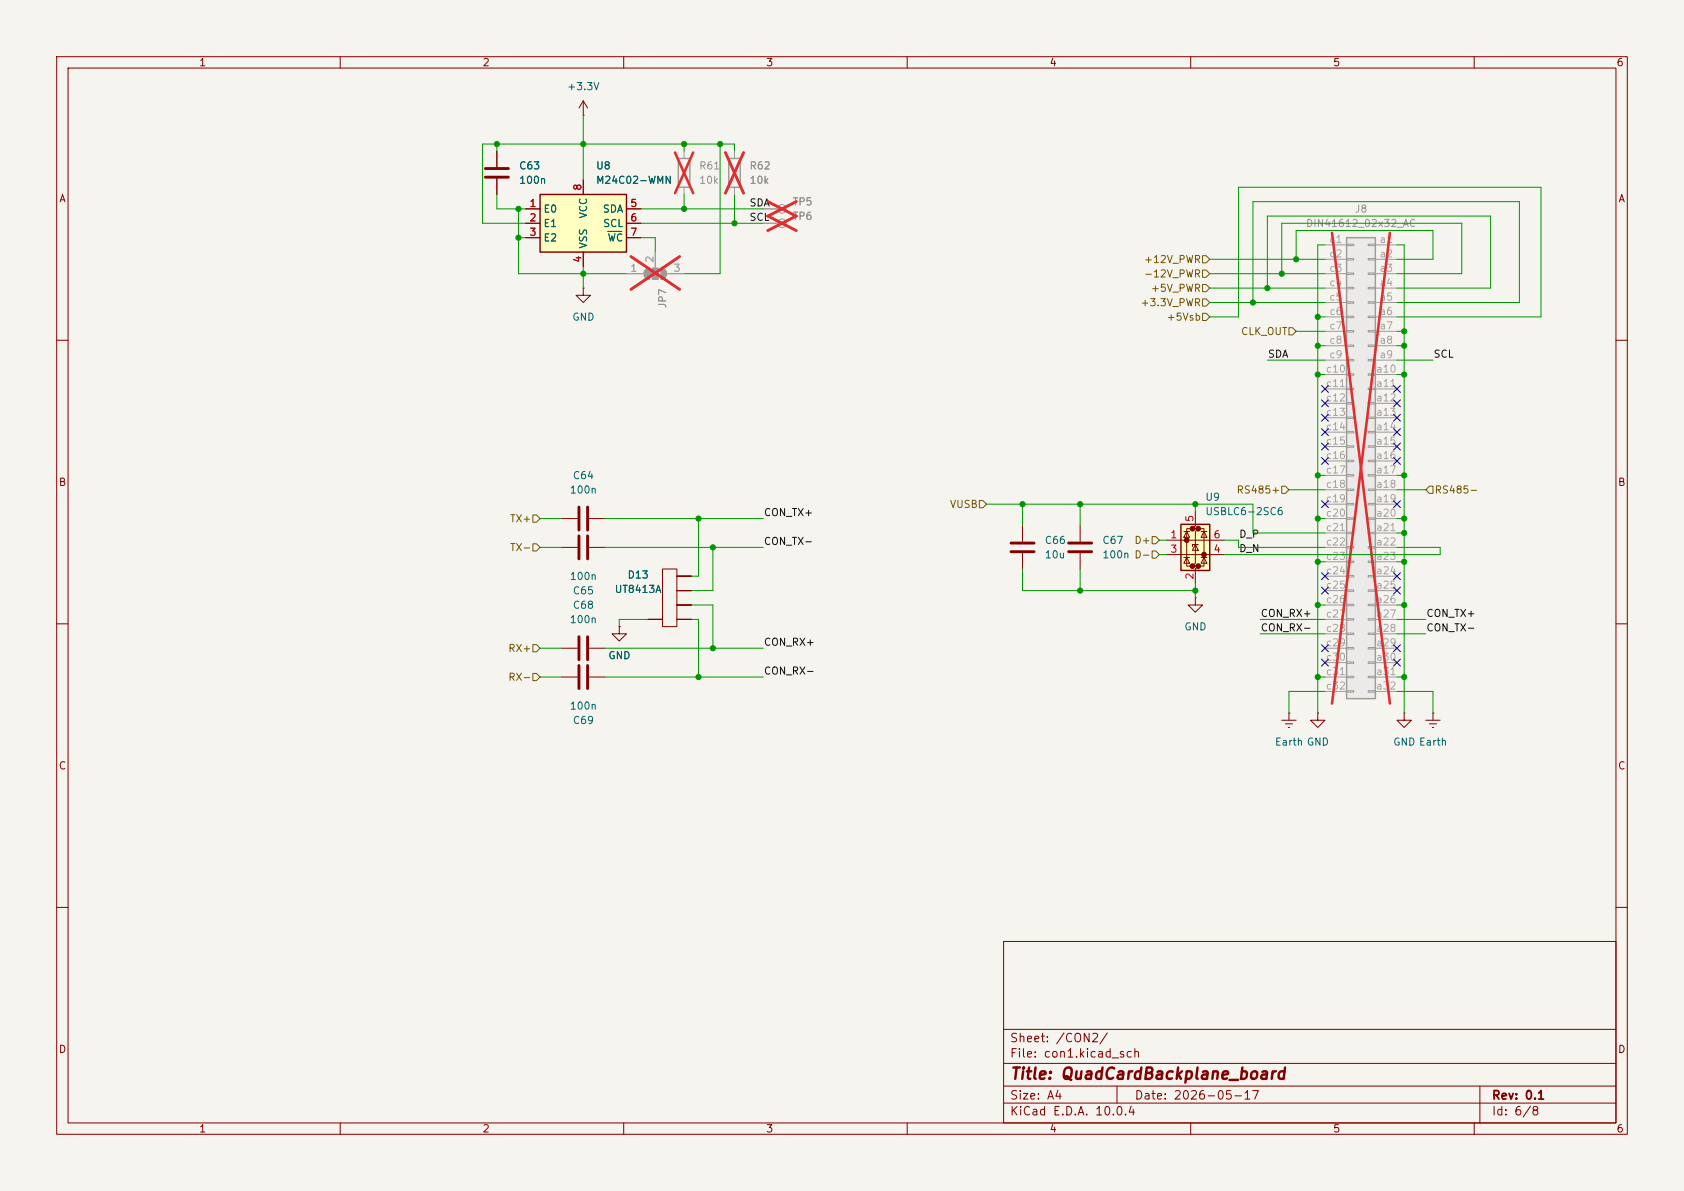
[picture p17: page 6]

CLK_OUT +5Vsb -12V_PWR +5V_PWR +12V_PWR | c4 | a4

c5 | a5
c6 c7 | a6


CLK_OUT +5Vsb -12V_PWR +5V_PWR +12V_PWR | c4 | a4

c5 | a5
c6 c7 | a6


CLK_OUT +5Vsb -12V_PWR +5V_PWR +12V_PWR | c4 | a4

c5 | a5
c6 c7 | a6

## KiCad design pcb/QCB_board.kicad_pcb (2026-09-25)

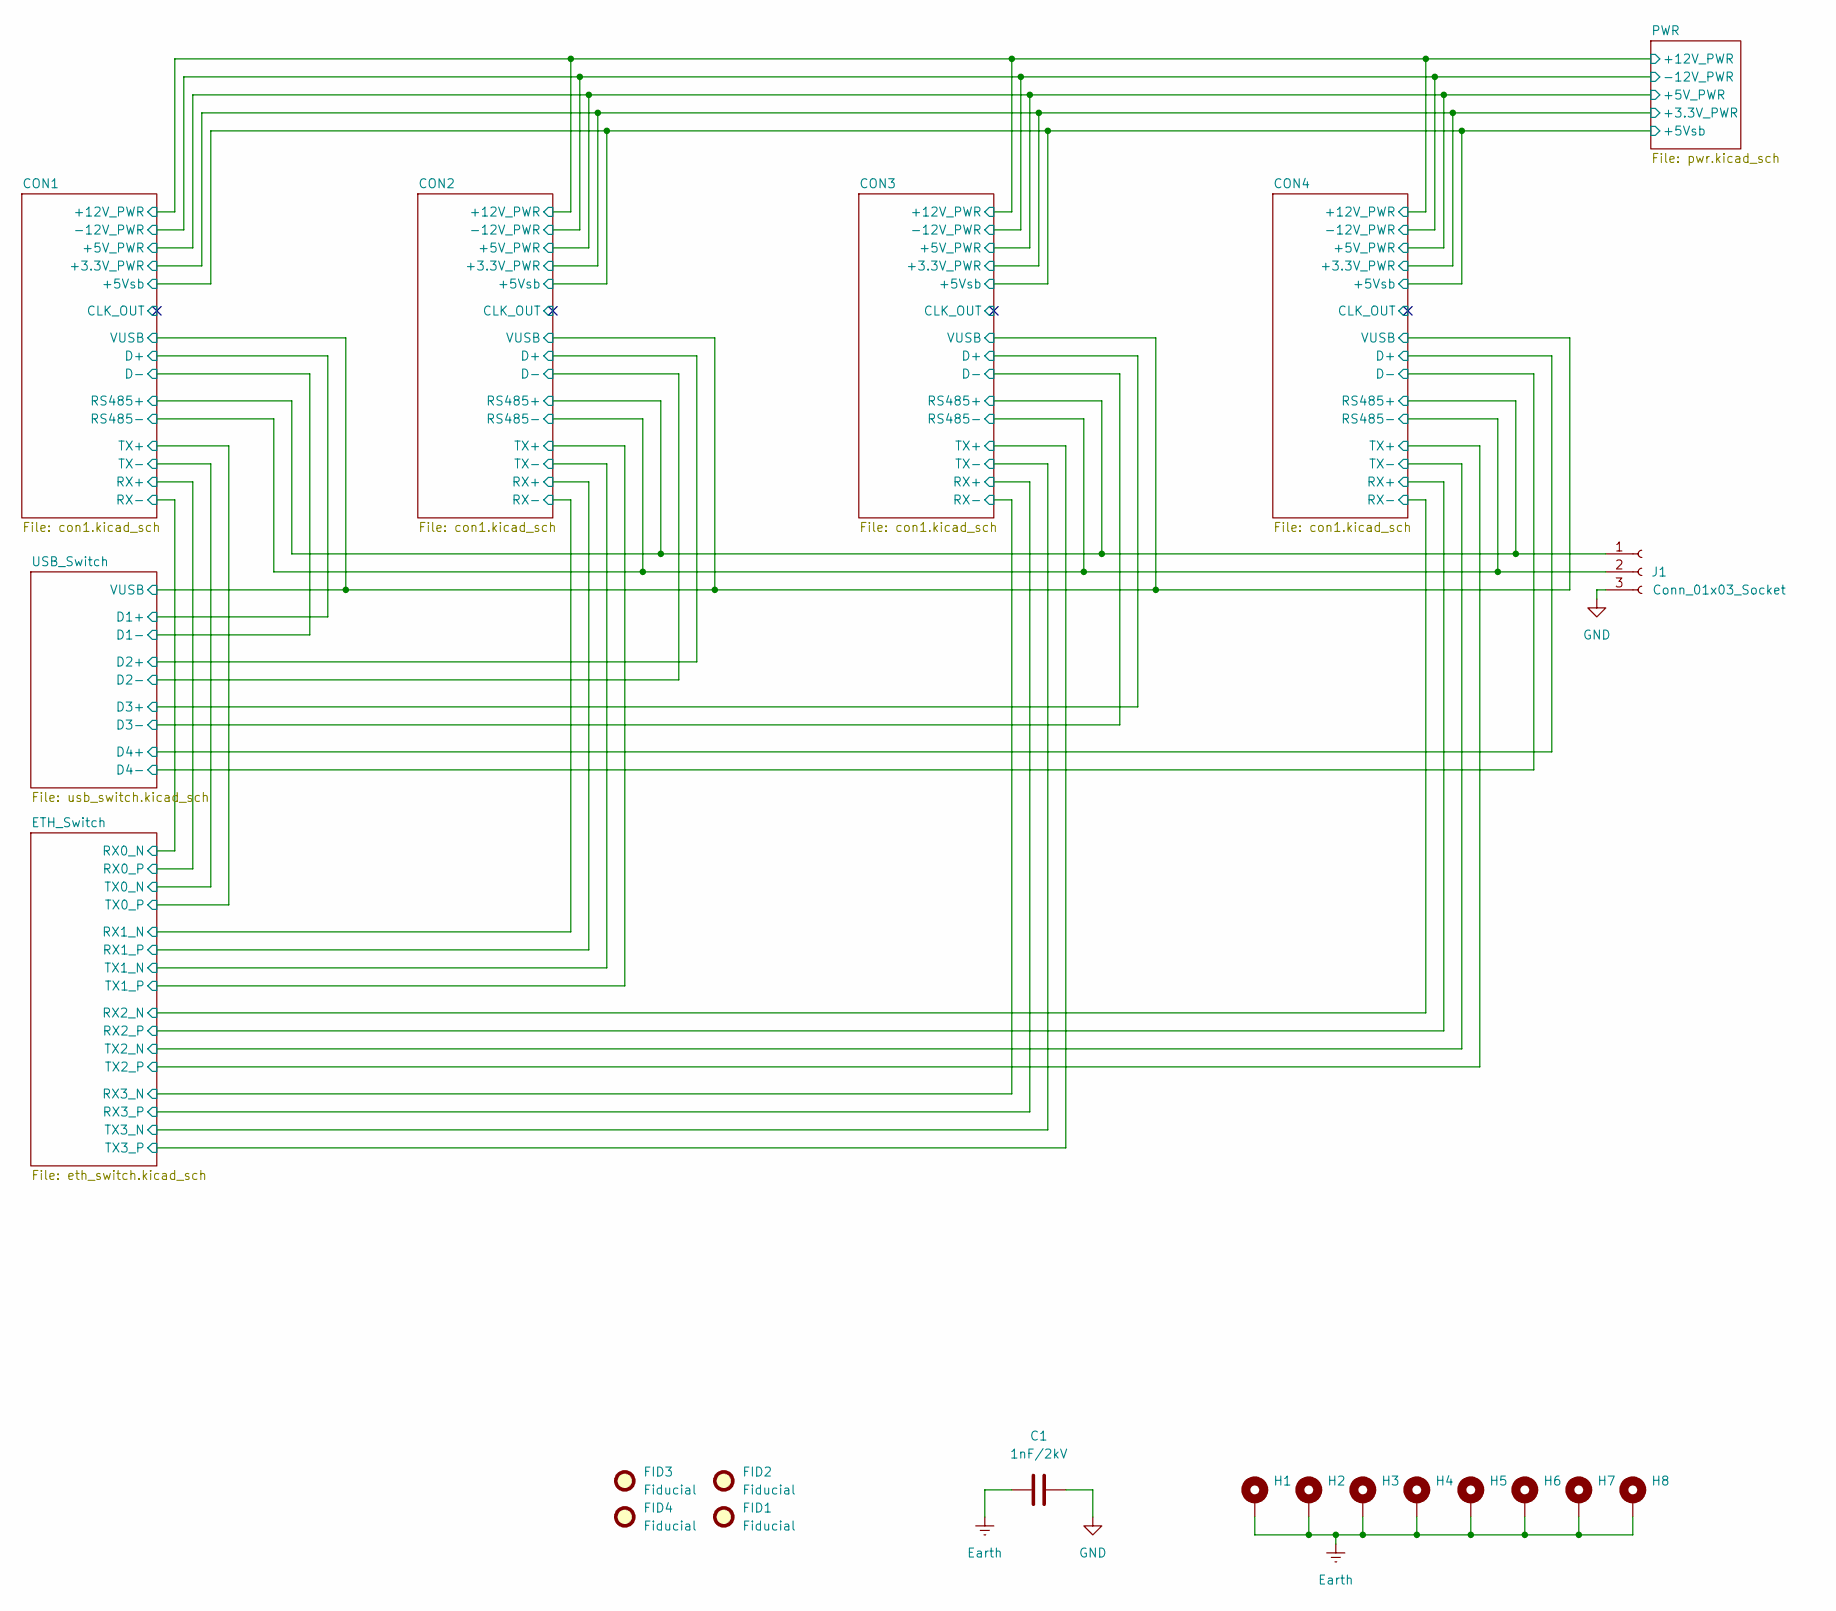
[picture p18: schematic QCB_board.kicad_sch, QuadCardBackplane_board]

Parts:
C1: 1nF/2kV; C_1206_3216Metric
FID1, FID2, FID3, FID4: Fiducial; Fiducial_0.5mm_Mask1mm
H1, H2, H3, H4, H5, H6, H7, H8: MountingHole_Pad; MountingHole_2.7mm_M2.5_DIN965_Pad
J1: Conn_01x03_Socket; JST_PH_B3B-PH-K_1x03_P2.00mm_Vertical

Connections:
/CON1/RS485+: J1.1; also elsewhere on the board
/CON1/RS485-: J1.2; also elsewhere on the board
Earth: C1.1, H1.1 (1_1), H2.1 (1_1), H3.1 (1_1), H4.1 (1_1), H5.1 (1_1), H6.1 (1_1), H7.1 (1_1), H8.1 (1_1); also elsewhere on the board
GND: C1.2, J1.3; also elsewhere on the board

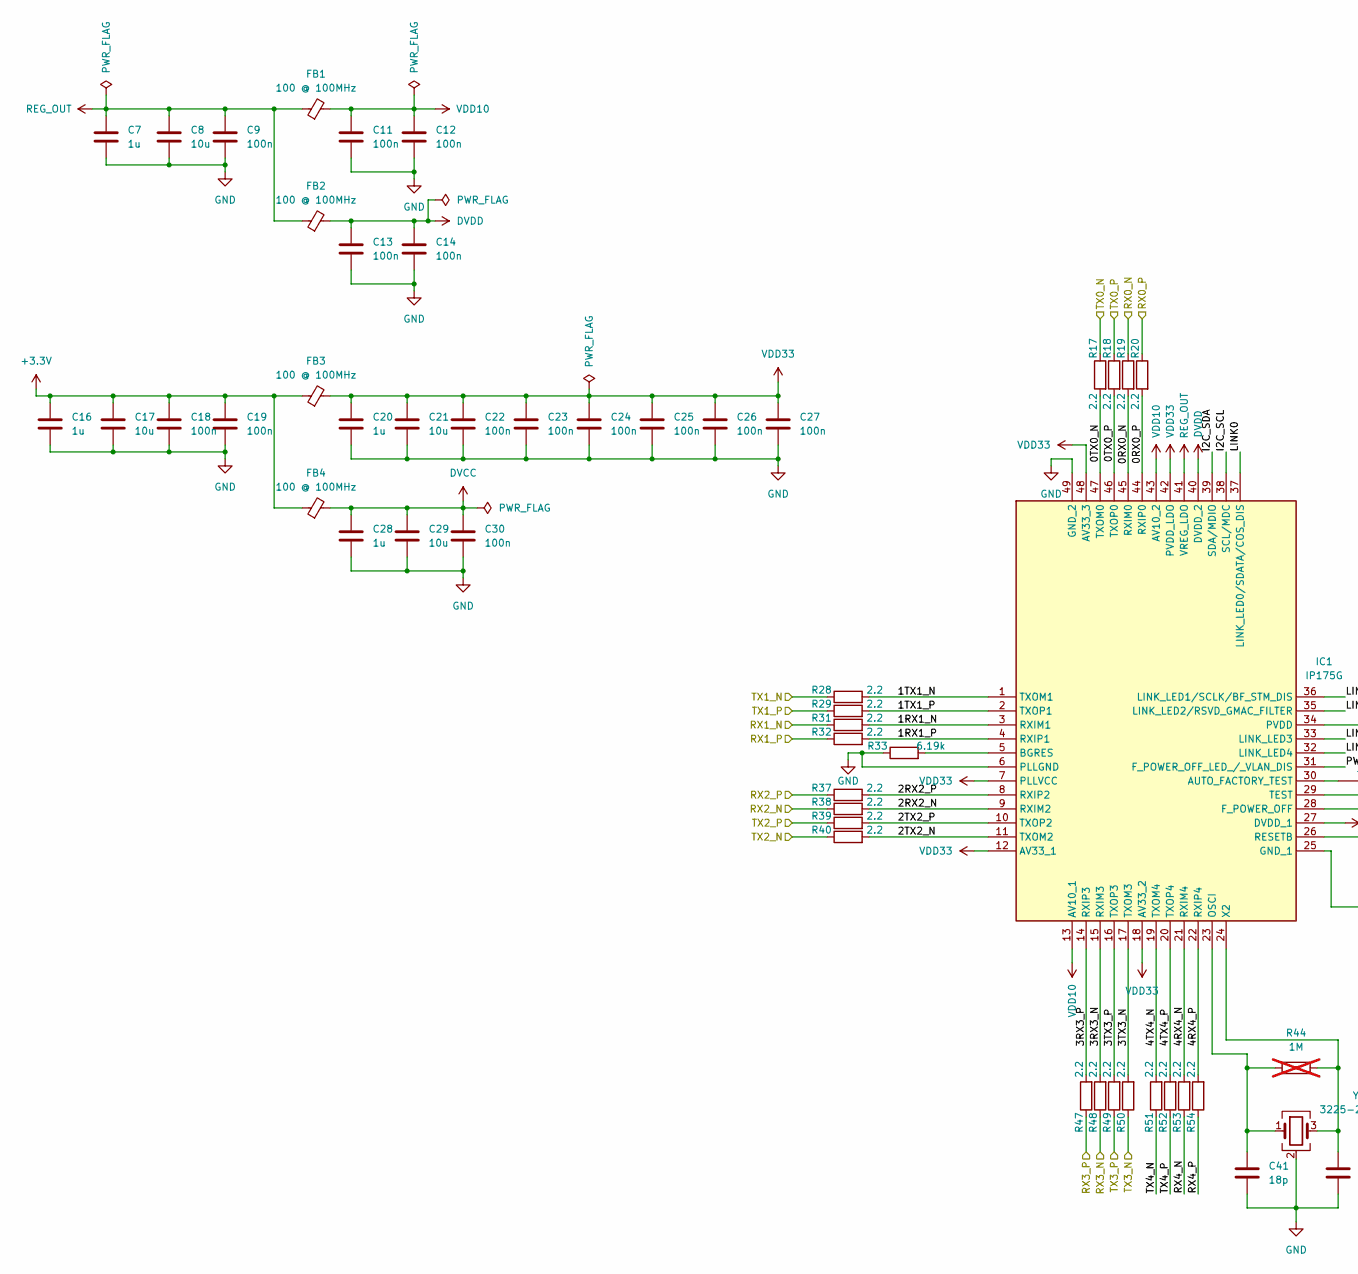
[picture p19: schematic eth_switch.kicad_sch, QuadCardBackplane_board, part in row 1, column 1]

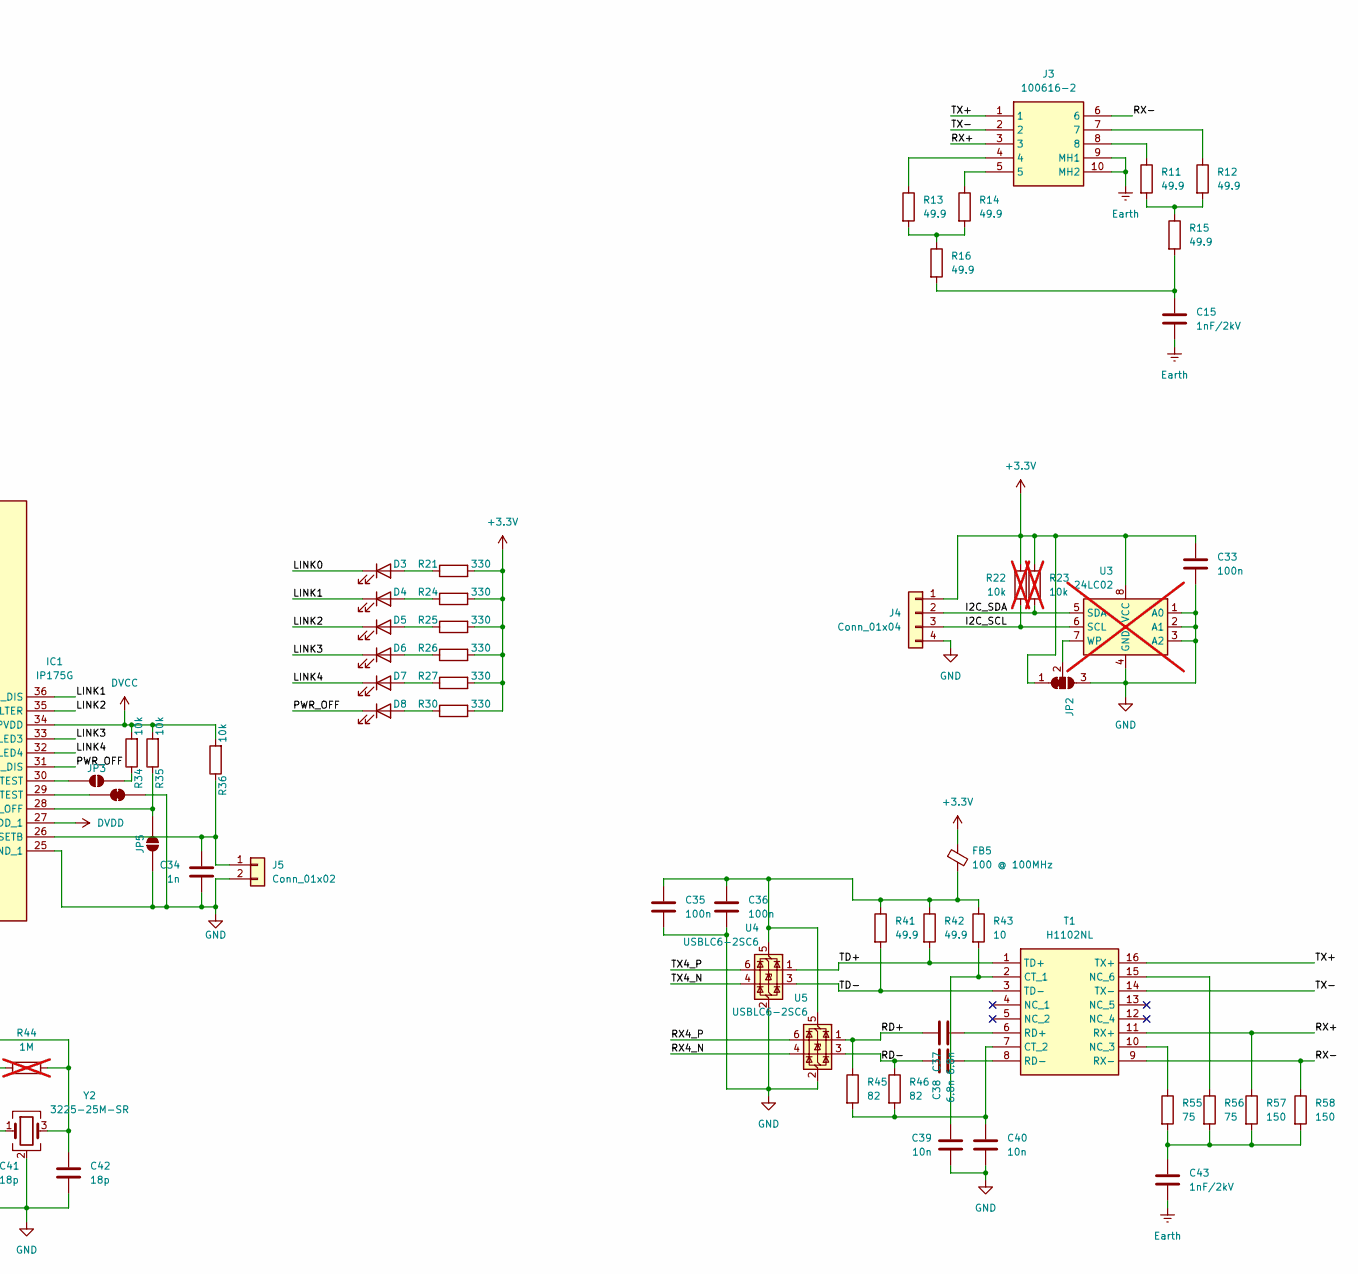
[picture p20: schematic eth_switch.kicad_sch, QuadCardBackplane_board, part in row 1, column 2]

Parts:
C7, C16, C20, C28: 1u; C_0603_1608Metric
C8, C17, C21, C29: 10u; C_1206_3216Metric
C9, C11, C12, C13, C14, C18, C19, C22, C23, C24, C25, C26, C27, C30, C33: 100n; C_0603_1608Metric
C15: 1nF/2kV; C_1206_3216Metric
C34: 1n; C_0603_1608Metric
C35, C36: 100n; C_0603_1608Metric; Manufacturer_Part_Number GRM188R71H104KA93D
C37, C38: 6.8n; C_0603_1608Metric
C39, C40: 10n; C_0603_1608Metric; Manufacturer_Part_Number GRM1885C1H103JA01J
C41, C42: 18p; C_0402_1005Metric
C43: 1nF/2kV; C_1206_3216Metric; Manufacturer_Part_Number 1206B102K202
D3, D4, D5, D6, D7, D8: LED_0603_1608Metric
FB1, FB2, FB3, FB4, FB5: 100 @ 100MHz; L_0603_1608Metric_Pad1.05x0.95mm_HandSolder; Manufacturer_Part_Number WLBD1608HCU101TL
IC1: IP175G; QFN40P600X600X90-49N-D; Manufacturer_Part_Number IP175G
J3: 100616-2; 1006162; Manufacturer_Part_Number 100616-2
J4: Conn_01x04; PinHeader_1x04_P1.00mm_Vertical
J5: Conn_01x02; PinHeader_1x02_P1.00mm_Vertical
JP2: SolderJumper_3_Bridged12; SolderJumper-3_P1.3mm_Bridged12_Pad1.0x1.5mm
JP3, JP5: SolderJumper_2_Open; SolderJumper-2_P1.3mm_Open_RoundedPad1.0x1.5mm
JP4: SolderJumper_2_Bridged; SolderJumper-2_P1.3mm_Bridged_RoundedPad1.0x1.5mm
R11, R12, R13, R14, R15, R16: 49.9; R_0603_1608Metric
R17, R18, R19, R20, R28, R29, R31, R32, R37, R38, R39, R40, R47, R48, R49, R50, R51, R52, R53, R54: 2.2; R_0603_1608Metric
R21, R24, R25, R26, R27, R30: 330; R_0603_1608Metric
R22, R23: 10k; R_0603_1608Metric; not fitted
R33: 6.19k; R_0603_1608Metric
R34, R35, R36: 10k; R_0603_1608Metric
R41, R42: 49.9; R_0603_1608Metric; Manufacturer_Part_Number CRCW060349R9FKTABC
R43: 10; R_0603_1608Metric
R44: 1M; R_0603_1608Metric; Manufacturer_Part_Number 0603SAF1004T5E; not fitted
R45, R46: 82; R_0603_1608Metric; Manufacturer_Part_Number RC0603JR-0782RL
R55, R56: 75; R_0603_1608Metric; Manufacturer_Part_Number 0603SAJ0750T5E
R57, R58: 150; R_0603_1608Metric; Manufacturer_Part_Number 1-2176339-5
T1: H1102NL; SOIC127P940X597-16N; Manufacturer_Part_Number H1102NL
U3: 24LC02; SOIC-8_3.9x4.9mm_P1.27mm; not fitted
U4, U5: USBLC6-2SC6; SOT-23-6_Handsoldering; Manufacturer_Part_Number USBLC6-2SC6
Y2: 3225-25M-SR; Crystal_SMD_3225-4Pin_3.2x2.5mm

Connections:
+3.3V: C16.1, C17.1, C18.1, C19.1, C33.1, FB3.1, FB4.1, FB5.1, J4.1, JP2.1 (A), R21.2, R22.2, R23.2, R24.2, R25.2, R26.2, R27.2, R30.2, U3.8 (VCC); also elsewhere on the board
/CON1/RX+: R20.1; also elsewhere on the board
/CON1/RX-: R19.1; also elsewhere on the board
/CON1/TX+: R18.1; also elsewhere on the board
/CON1/TX-: R17.1; also elsewhere on the board
/CON2/RX+: R32.1; also elsewhere on the board
/CON2/RX-: R31.1; also elsewhere on the board
/CON2/TX+: R29.1; also elsewhere on the board
/CON2/TX-: R28.1; also elsewhere on the board
/CON3/RX+: R47.1; also elsewhere on the board
/CON3/RX-: R48.1; also elsewhere on the board
/CON3/TX+: R49.1; also elsewhere on the board
/CON3/TX-: R50.1; also elsewhere on the board
/CON4/RX+: R37.1; also elsewhere on the board
/CON4/RX-: R38.1; also elsewhere on the board
/CON4/TX+: R39.1; also elsewhere on the board
/CON4/TX-: R40.1; also elsewhere on the board
/ETH_Switch/0RX0_N: IC1.45 (RXIM0), R19.2
/ETH_Switch/0RX0_P: IC1.44 (RXIP0), R20.2
/ETH_Switch/0TX0_N: IC1.47 (TXOM0), R17.2
/ETH_Switch/0TX0_P: IC1.46 (TXOP0), R18.2
/ETH_Switch/1RX1_N: IC1.3 (RXIM1), R31.2
/ETH_Switch/1RX1_P: IC1.4 (RXIP1), R32.2
/ETH_Switch/1TX1_N: IC1.1 (TXOM1), R28.2
/ETH_Switch/1TX1_P: IC1.2 (TXOP1), R29.2
/ETH_Switch/2RX2_N: IC1.9 (RXIM2), R38.2
/ETH_Switch/2RX2_P: IC1.8 (RXIP2), R37.2
/ETH_Switch/2TX2_N: IC1.11 (TXOM2), R40.2
/ETH_Switch/2TX2_P: IC1.10 (TXOP2), R39.2
/ETH_Switch/3RX3_N: IC1.15 (RXIM3), R48.2
/ETH_Switch/3RX3_P: IC1.14 (RXIP3), R47.2
/ETH_Switch/3TX3_N: IC1.17 (TXOM3), R50.2
/ETH_Switch/3TX3_P: IC1.16 (TXOP3), R49.2
/ETH_Switch/4RX4_N: IC1.21 (RXIM4), R53.2
/ETH_Switch/4RX4_P: IC1.22 (RXIP4), R54.2
/ETH_Switch/4TX4_N: IC1.19 (TXOM4), R51.2
/ETH_Switch/4TX4_P: IC1.20 (TXOP4), R52.2
/ETH_Switch/I2C_SCL: IC1.38 (SCL/MDC), J4.3, R22.1, U3.6 (SCL)
/ETH_Switch/I2C_SDA: IC1.39 (SDA/MDIO), J4.2, R23.1, U3.5 (SDA)
/ETH_Switch/LINK0: D3.1 (K), IC1.37 (LINK_LED0/SDATA/COS_DIS)
/ETH_Switch/LINK1: D4.1 (K), IC1.36 (LINK_LED1/SCLK/BF_STM_DIS)
/ETH_Switch/LINK2: D5.1 (K), IC1.35 (LINK_LED2/RSVD_GMAC_FILTER)
/ETH_Switch/LINK3: D6.1 (K), IC1.33 (LINK_LED3)
/ETH_Switch/LINK4: D7.1 (K), IC1.32 (LINK_LED4)
/ETH_Switch/PWR_OFF: D8.1 (K), IC1.31 (F_POWER_OFF_LED_/_VLAN_DIS)
/ETH_Switch/RD+: C37.2, R45.1, U5.1 (I/O1)
/ETH_Switch/RD-: C38.2, R46.1, U5.3 (I/O2)
/ETH_Switch/RX4_N: R53.1, U5.4 (I/O2)
/ETH_Switch/RX4_P: R54.1, U5.6 (I/O1)
/ETH_Switch/RX+: J3.3, R57.1, T1.11 (RX+)
/ETH_Switch/RX-: J3.6, R58.1, T1.9 (RX-)
/ETH_Switch/TD+: R42.2, T1.1 (TD+), U4.1 (I/O1)
/ETH_Switch/TD-: R41.2, T1.3 (TD-), U4.3 (I/O2)
/ETH_Switch/TX4_N: R51.1, U4.4 (I/O2)
/ETH_Switch/TX4_P: R52.1, U4.6 (I/O1)
/ETH_Switch/TX+: J3.1, T1.16 (TX+)
/ETH_Switch/TX-: J3.2, T1.14 (TX-)
DVCC: C28.1, C29.1, C30.1, FB4.2, IC1.34 (PVDD), R34.2, R35.2, R36.2
DVDD: C13.1, C14.1, FB2.2, IC1.27 (DVDD_1), IC1.40 (DVDD_2)
Earth: C15.2, C43.2, J3.9 (MH1), J3.10 (MH2); also elsewhere on the board
GND: C7.2, C8.2, C9.2, C11.2, C12.2, C13.2, C14.2, C16.2, C17.2, C18.2, C19.2, C20.2, C21.2, C22.2, C23.2, C24.2, C25.2, C26.2, C27.2, C28.2, C29.2, C30.2, C33.2, C34.1, C35.2, C36.2, C39.1, C40.2, C41.2, C42.2, IC1.6 (PLLGND), IC1.25 (GND_1), IC1.49 (GND_2), J4.4, J5.2, JP2.3 (B), JP4.2 (B), JP5.1 (A), R33.1, U3.1 (A0), U3.2 (A1), U3.3 (A2), U3.4 (GND), U4.2 (GND), U5.2 (GND), Y2.2 (G), Y2.4 (G); also elsewhere on the board
unnamed: C15.1, R15.2, R16.2
unnamed: C43.1, R55.2, R56.2, R57.2, R58.2
unnamed: D3.2 (A), R21.1
unnamed: D4.2 (A), R24.1
unnamed: D5.2 (A), R25.1
unnamed: D6.2 (A), R26.1
unnamed: D7.2 (A), R27.1
unnamed: D8.2 (A), R30.1
unnamed: IC1.30 (AUTO_FACTORY_TEST), JP3.1 (A)
unnamed: IC1.5 (BGRES), R33.2
unnamed: IC1.28 (F_POWER_OFF), JP5.2 (B), R35.1
unnamed: C41.1, IC1.23 (OSCI), R44.1, Y2.1
unnamed: C34.2, IC1.26 (RESETB), J5.1, R36.1
unnamed: IC1.29 (TEST), JP4.1 (A)
unnamed: C42.1, IC1.24 (X2), R44.2, Y2.3
unnamed: J3.4, R13.1
unnamed: J3.5, R14.1
unnamed: J3.7, R12.1
unnamed: J3.8, R11.1
unnamed: JP2.2 (C), U3.7 (WP)
unnamed: JP3.2 (B), R34.1
unnamed: R11.2, R12.2, R15.1
unnamed: R13.2, R14.2, R16.1
unnamed: C39.2, R43.2, T1.2 (CT_1)
unnamed: C40.1, R45.2, R46.2, T1.7 (CT_2)
unnamed: R55.1, T1.10 (NC_3)
unnamed: R56.1, T1.15 (NC_6)
unnamed: C37.1, T1.6 (RD+)
unnamed: C38.1, T1.8 (RD-)
unnamed: C35.1, C36.1, FB5.2, R41.1, R42.1, R43.1, U4.5 (VBUS), U5.5 (VBUS)
REG_OUT: C7.1, C8.1, C9.1, FB1.1, FB2.1, IC1.41 (VREG_LDO)
VDD10: C11.1, C12.1, FB1.2, IC1.13 (AV10_1), IC1.43 (AV10_2)
VDD33: C20.1, C21.1, C22.1, C23.1, C24.1, C25.1, C26.1, C27.1, FB3.2, IC1.7 (PLLVCC), IC1.12 (AV33_1), IC1.18 (AV33_2), IC1.42 (PVDD_LDO), IC1.48 (AV33_3)

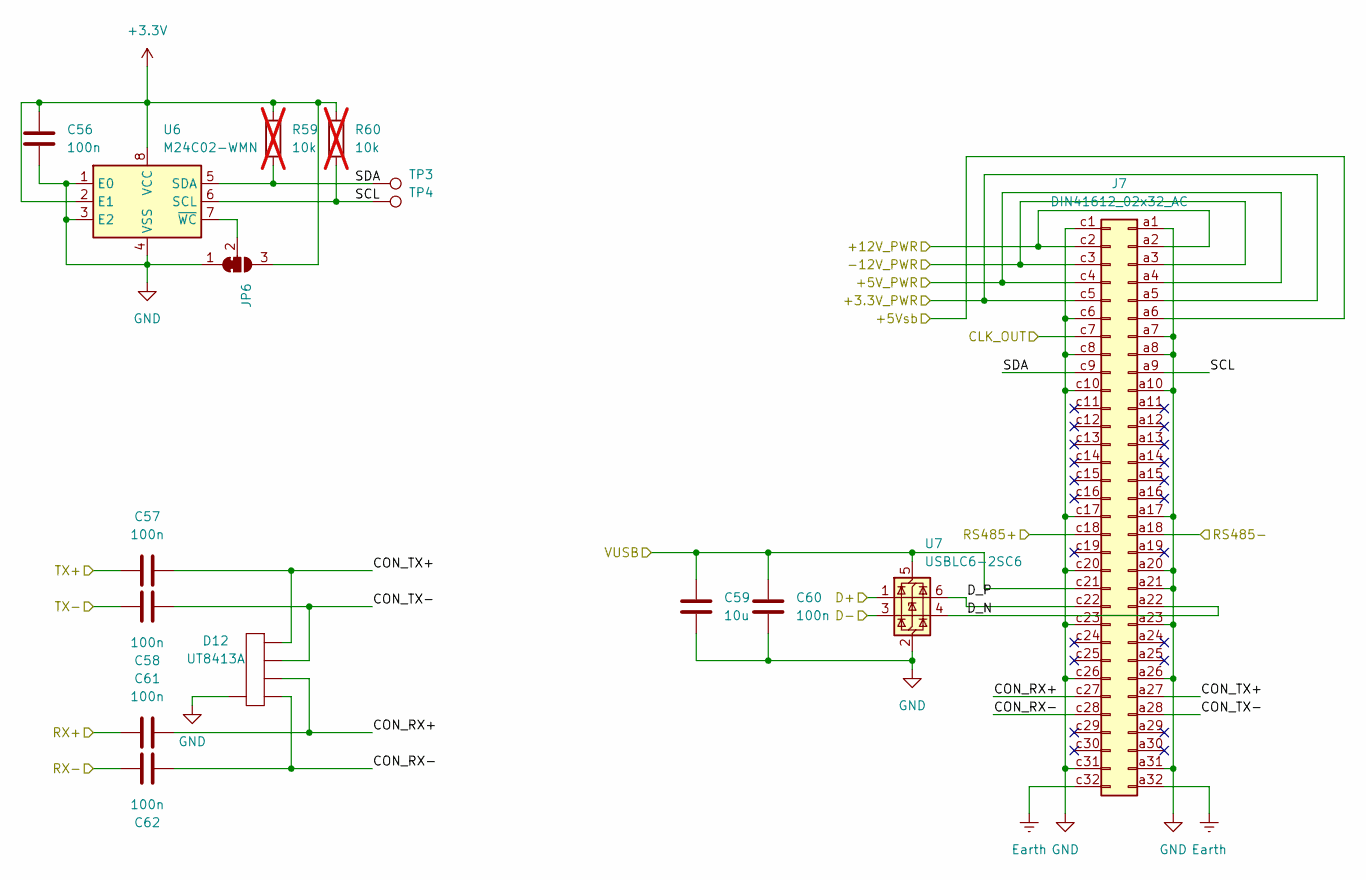
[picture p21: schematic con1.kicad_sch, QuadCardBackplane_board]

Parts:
C56, C60: 100n; C_0603_1608Metric
C57, C58, C61, C62: 100n; C_0805_2012Metric
C59: 10u; C_1206_3216Metric
D12: UT8413A; Diodes_UDFN-10_1x2.5mm_P0.5mm; Manufacturer_Part_Number UT8413A
J7: DIN41612_02x32_AC; DIN41612_C_2x32_Female_Vertical_THT
JP6: SolderJumper_3_Bridged12; SolderJumper-3_P1.3mm_Bridged12_Pad1.0x1.5mm
R59, R60: 10k; R_0603_1608Metric; not fitted
TP3, TP4: TestPoint; TestPoint_Pad_D1.0mm
U6: M24C02-WMN; SOIC-8_3.9x4.9mm_P1.27mm
U7: USBLC6-2SC6; SOT-23-6_Handsoldering

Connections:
+3.3V: C56.2, JP6.3 (B), R59.2, R60.2, U6.2 (E1), U6.8 (VCC); also elsewhere on the board
/CON1/+3.3V_PWR: J7.a5, J7.c5; also elsewhere on the board
/CON1/+5V_PWR: J7.a4, J7.c4; also elsewhere on the board
/CON1/+5Vsb: J7.a6; also elsewhere on the board
/CON1/+12V_PWR: J7.a2, J7.c2; also elsewhere on the board
/CON1/-12V_PWR: J7.a3, J7.c3; also elsewhere on the board
/CON1/CLK_OUT: J7.c7
/CON1/CON_RX+: C61.2, D12.2, D12.9, J7.c27
/CON1/CON_RX-: C62.2, D12.1, D12.10, J7.c28
/CON1/CON_TX+: C57.2, D12.5, D12.6, J7.a27
/CON1/CON_TX-: C58.2, D12.4, D12.7, J7.a28
/CON1/D+: U7.1 (I/O1); also elsewhere on the board
/CON1/D-: U7.3 (I/O2); also elsewhere on the board
/CON1/D_N: J7.a22, U7.4 (I/O2)
/CON1/D_P: J7.c22, U7.6 (I/O1)
/CON1/RS485+: J7.c18; also elsewhere on the board
/CON1/RS485-: J7.a18; also elsewhere on the board
/CON1/RX+: C61.1; also elsewhere on the board
/CON1/RX-: C62.1; also elsewhere on the board
/CON1/SCL: J7.a9, R60.1, TP4.1 (1_1), U6.6 (SCL)
/CON1/SDA: J7.c9, R59.1, TP3.1 (1_1), U6.5 (SDA)
/CON1/TX+: C57.1; also elsewhere on the board
/CON1/TX-: C58.1; also elsewhere on the board
/CON1/VUSB: C59.1, C60.2, J7.c21, U7.5 (VBUS); also elsewhere on the board
Earth: J7.a32, J7.c32; also elsewhere on the board
GND: C56.1, C59.2, C60.1, D12.3, D12.8, J7.a1, J7.a7, J7.a8, J7.a10, J7.a17, J7.a20, J7.a21, J7.a23, J7.a26, J7.a31, J7.c1, J7.c6, J7.c8, J7.c10, J7.c17, J7.c20, J7.c23, J7.c26, J7.c31, JP6.1 (A), U6.1 (E0), U6.3 (E2), U6.4 (VSS), U7.2 (GND); also elsewhere on the board
unnamed: JP6.2 (C), U6.7 (~WC)

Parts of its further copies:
C63, C67, C70, C74, C77, C81: 100n; C_0603_1608Metric
C64, C65, C68, C69, C71, C72, C75, C76, C78, C79, C82, C83: 100n; C_0805_2012Metric
C66, C73, C80: 10u; C_1206_3216Metric
D13, D14, D15: UT8413A; Diodes_UDFN-10_1x2.5mm_P0.5mm; Manufacturer_Part_Number UT8413A
J8, J9, J10: DIN41612_02x32_AC; DIN41612_C_2x32_Female_Vertical_THT
JP7, JP8, JP9: SolderJumper_3_Bridged12; SolderJumper-3_P1.3mm_Bridged12_Pad1.0x1.5mm
R61, R62, R63, R64, R65, R66: 10k; R_0603_1608Metric; not fitted
TP5, TP6, TP7, TP8, TP9, TP10: TestPoint; TestPoint_Pad_D1.0mm
U8, U10, U12: M24C02-WMN; SOIC-8_3.9x4.9mm_P1.27mm
U9, U11, U13: USBLC6-2SC6; SOT-23-6_Handsoldering

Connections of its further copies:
+3.3V: C63.2, C70.2, C77.2, JP7.3 (B), JP8.3 (B), JP9.3 (B), R61.2, R62.2, R63.2, R64.2, R65.2, R66.2, U8.2 (E1), U8.8 (VCC), U10.2 (E1), U10.8 (VCC), U12.2 (E1), U12.8 (VCC); also elsewhere on the board
/CON1/+3.3V_PWR: J8.a5, J8.c5, J9.a5, J9.c5, J10.a5, J10.c5; also elsewhere on the board
/CON1/+5V_PWR: J8.a4, J8.c4, J9.a4, J9.c4, J10.a4, J10.c4; also elsewhere on the board
/CON1/+5Vsb: J8.a6, J9.a6, J10.a6; also elsewhere on the board
/CON1/+12V_PWR: J8.a2, J8.c2, J9.a2, J9.c2, J10.a2, J10.c2; also elsewhere on the board
/CON1/-12V_PWR: J8.a3, J8.c3, J9.a3, J9.c3, J10.a3, J10.c3; also elsewhere on the board
/CON1/RS485+: J8.c18, J9.c18, J10.c18; also elsewhere on the board
/CON1/RS485-: J8.a18, J9.a18, J10.a18; also elsewhere on the board
/CON1/VUSB: C66.1, C67.2, C73.1, C74.2, C80.1, C81.2, J8.c21, J9.c21, J10.c21, U9.5 (VBUS), U11.5 (VBUS), U13.5 (VBUS); also elsewhere on the board
/CON2/CLK_OUT: J8.c7
/CON2/CON_RX+: C68.2, D13.2, D13.9, J8.c27
/CON2/CON_RX-: C69.2, D13.1, D13.10, J8.c28
/CON2/CON_TX+: C64.2, D13.5, D13.6, J8.a27
/CON2/CON_TX-: C65.2, D13.4, D13.7, J8.a28
/CON2/D+: U9.1 (I/O1); also elsewhere on the board
/CON2/D-: U9.3 (I/O2); also elsewhere on the board
/CON2/D_N: J8.a22, U9.4 (I/O2)
/CON2/D_P: J8.c22, U9.6 (I/O1)
/CON2/RX+: C68.1; also elsewhere on the board
/CON2/RX-: C69.1; also elsewhere on the board
/CON2/SCL: J8.a9, R62.1, TP6.1 (1_1), U8.6 (SCL)
/CON2/SDA: J8.c9, R61.1, TP5.1 (1_1), U8.5 (SDA)
/CON2/TX+: C64.1; also elsewhere on the board
/CON2/TX-: C65.1; also elsewhere on the board
/CON3/CLK_OUT: J9.c7
/CON3/CON_RX+: C75.2, D14.2, D14.9, J9.c27
/CON3/CON_RX-: C76.2, D14.1, D14.10, J9.c28
/CON3/CON_TX+: C71.2, D14.5, D14.6, J9.a27
/CON3/CON_TX-: C72.2, D14.4, D14.7, J9.a28
/CON3/D+: U11.1 (I/O1); also elsewhere on the board
/CON3/D-: U11.3 (I/O2); also elsewhere on the board
/CON3/D_N: J9.a22, U11.4 (I/O2)
/CON3/D_P: J9.c22, U11.6 (I/O1)
/CON3/RX+: C75.1; also elsewhere on the board
/CON3/RX-: C76.1; also elsewhere on the board
/CON3/SCL: J9.a9, R64.1, TP8.1 (1_1), U10.6 (SCL)
/CON3/SDA: J9.c9, R63.1, TP7.1 (1_1), U10.5 (SDA)
/CON3/TX+: C71.1; also elsewhere on the board
/CON3/TX-: C72.1; also elsewhere on the board
/CON4/CLK_OUT: J10.c7
/CON4/CON_RX+: C82.2, D15.2, D15.9, J10.c27
/CON4/CON_RX-: C83.2, D15.1, D15.10, J10.c28
/CON4/CON_TX+: C78.2, D15.5, D15.6, J10.a27
/CON4/CON_TX-: C79.2, D15.4, D15.7, J10.a28
/CON4/D+: U13.1 (I/O1); also elsewhere on the board
/CON4/D-: U13.3 (I/O2); also elsewhere on the board
/CON4/D_N: J10.a22, U13.4 (I/O2)
/CON4/D_P: J10.c22, U13.6 (I/O1)
/CON4/RX+: C82.1; also elsewhere on the board
/CON4/RX-: C83.1; also elsewhere on the board
/CON4/SCL: J10.a9, R66.1, TP10.1 (1_1), U12.6 (SCL)
/CON4/SDA: J10.c9, R65.1, TP9.1 (1_1), U12.5 (SDA)
/CON4/TX+: C78.1; also elsewhere on the board
/CON4/TX-: C79.1; also elsewhere on the board
Earth: J8.a32, J8.c32, J9.a32, J9.c32, J10.a32, J10.c32; also elsewhere on the board
GND: C63.1, C66.2, C67.1, C70.1, C73.2, C74.1, C77.1, C80.2, C81.1, D13.3, D13.8, D14.3, D14.8, D15.3, D15.8, J8.a1, J8.a7, J8.a8, J8.a10, J8.a17, J8.a20, J8.a21, J8.a23, J8.a26, J8.a31, J8.c1, J8.c6, J8.c8, J8.c10, J8.c17, J8.c20, J8.c23, J8.c26, J8.c31, J9.a1, J9.a7, J9.a8, J9.a10, J9.a17, J9.a20, J9.a21, J9.a23, J9.a26, J9.a31, J9.c1, J9.c6, J9.c8, J9.c10, J9.c17, J9.c20, J9.c23, J9.c26, J9.c31, J10.a1, J10.a7, J10.a8, J10.a10, J10.a17, J10.a20, J10.a21, J10.a23, J10.a26, J10.a31, J10.c1, J10.c6, J10.c8, J10.c10, J10.c17, J10.c20, J10.c23, J10.c26, J10.c31, JP7.1 (A), JP8.1 (A), JP9.1 (A), U8.1 (E0), U8.3 (E2), U8.4 (VSS), U9.2 (GND), U10.1 (E0), U10.3 (E2), U10.4 (VSS), U11.2 (GND), U12.1 (E0), U12.3 (E2), U12.4 (VSS), U13.2 (GND); also elsewhere on the board
unnamed: JP7.2 (C), U8.7 (~WC)
unnamed: JP8.2 (C), U10.7 (~WC)
unnamed: JP9.2 (C), U12.7 (~WC)

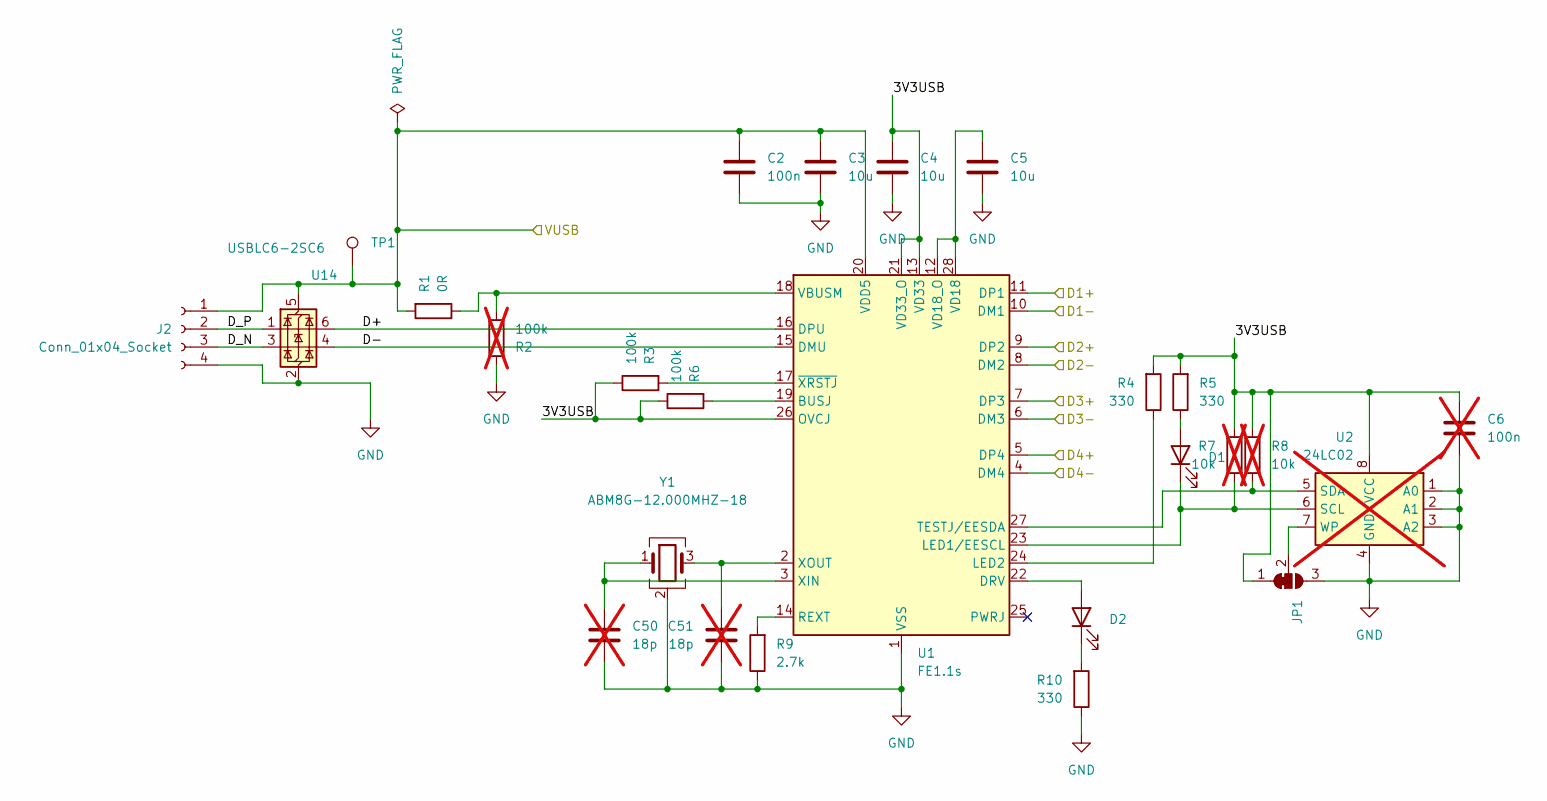
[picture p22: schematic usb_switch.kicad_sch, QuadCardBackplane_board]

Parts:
C2: 100n; C_0603_1608Metric
C3, C4, C5: 10u; C_1206_3216Metric
C6: 100n; C_0603_1608Metric; not fitted
C50, C51: 18p; C_0402_1005Metric; not fitted
D1, D2: LED_0603_1608Metric
J2: Conn_01x04_Socket; JST_PH_B4B-PH-K_1x04_P2.00mm_Vertical
JP1: SolderJumper_3_Bridged12; SolderJumper-3_P1.3mm_Bridged12_Pad1.0x1.5mm
R1: 0R; R_0603_1608Metric
R2: 100k; R_0603_1608Metric; not fitted
R3, R6: 100k; R_0603_1608Metric
R4, R5, R10: 330; R_0603_1608Metric
R7, R8: 10k; R_0603_1608Metric; not fitted
R9: 2.7k; R_0603_1608Metric
TP1: TestPoint; TestPoint_Pad_D1.0mm
U1: FE1.1s; SSOP-28_3.9x9.9mm_P0.635mm
U2: 24LC02; SOIC-8_3.9x4.9mm_P1.27mm; not fitted
U14: USBLC6-2SC6; SOT-23-6_Handsoldering; Manufacturer_Part_Number USBLC6-2SC6
Y1: ABM8G-12.000MHZ-18; Crystal_SMD_Abracon_ABM8G-4Pin_3.2x2.5mm

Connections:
/CON1/D+: U1.11 (DP1); also elsewhere on the board
/CON1/D-: U1.10 (DM1); also elsewhere on the board
/CON1/VUSB: C2.1, C3.1, J2.1, R1.2, TP1.1 (1_1), U1.20 (VDD5), U14.5 (VBUS); also elsewhere on the board
/CON2/D+: U1.9 (DP2); also elsewhere on the board
/CON2/D-: U1.8 (DM2); also elsewhere on the board
/CON3/D+: U1.7 (DP3); also elsewhere on the board
/CON3/D-: U1.6 (DM3); also elsewhere on the board
/CON4/D+: U1.5 (DP4); also elsewhere on the board
/CON4/D-: U1.4 (DM4); also elsewhere on the board
/USB_Switch/3V3USB: C4.1, C6.1, JP1.1 (A), R3.1, R4.2, R5.2, R6.1, R7.2, R8.2, U1.13 (VD33), U1.21 (VD33_O), U1.26 (OVCJ), U2.8 (VCC)
/USB_Switch/D+: U1.16 (DPU), U14.6 (I/O1)
/USB_Switch/D-: U1.15 (DMU), U14.4 (I/O2)
/USB_Switch/D_N: J2.3, U14.3 (I/O2)
/USB_Switch/D_P: J2.2, U14.1 (I/O1)
GND: C2.2, C3.2, C4.2, C5.2, C6.2, C50.2, C51.2, J2.4, JP1.3 (B), R2.2, R9.1, R10.1, U1.1 (VSS), U2.1 (A0), U2.2 (A1), U2.3 (A2), U2.4 (GND), U14.2 (GND), Y1.2 (G), Y1.4 (G); also elsewhere on the board
unnamed: D1.2 (A), R5.1
unnamed: D1.1 (K), R7.1, U1.23 (LED1/EESCL), U2.6 (SCL)
unnamed: D2.2 (A), U1.22 (DRV)
unnamed: D2.1 (K), R10.2
unnamed: JP1.2 (C), U2.7 (WP)
unnamed: R6.2, U1.19 (BUSJ)
unnamed: R4.1, U1.24 (LED2)
unnamed: R9.2, U1.14 (REXT)
unnamed: R8.1, U1.27 (TESTJ/EESDA), U2.5 (SDA)
unnamed: R1.1, R2.1, U1.18 (VBUSM)
unnamed: C5.1, U1.12 (VD18_O), U1.28 (VD18)
unnamed: C50.1, U1.3 (XIN), Y1.1
unnamed: C51.1, U1.2 (XOUT), Y1.3
unnamed: R3.2, U1.17 (~XRSTJ)

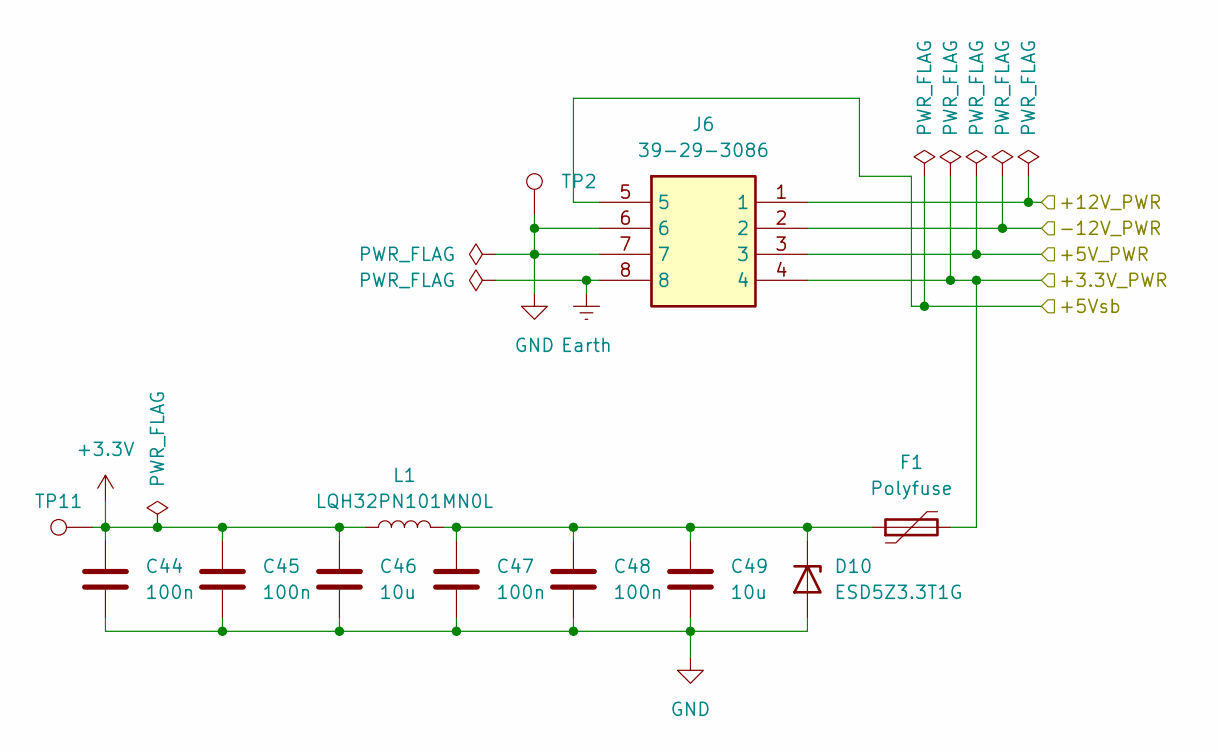
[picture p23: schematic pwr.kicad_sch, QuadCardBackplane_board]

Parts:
C44, C45, C47, C48: 100n; C_0603_1608Metric
C46, C49: 10u; C_1206_3216Metric
D10: ESD5Z3.3T1G; D_SOD-523
F1: Polyfuse; Fuse_1206_3216Metric_Pad1.42x1.75mm_HandSolder
J6: 39-29-3086; Molex_Mini-Fit_Jr_5566-08A_2x04_P4.20mm_Vertical; Manufacturer_Part_Number 39-29-3086
L1: LQH32PN101MN0L; L_1210_3225Metric
TP2, TP11: TestPoint; TestPoint_Pad_D1.0mm

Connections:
+3.3V: C44.1, C45.1, C46.1, L1.1, TP11.1 (1_1); also elsewhere on the board
/CON1/+3.3V_PWR: F1.2, J6.4; also elsewhere on the board
/CON1/+5V_PWR: J6.3; also elsewhere on the board
/CON1/+5Vsb: J6.5; also elsewhere on the board
/CON1/+12V_PWR: J6.1; also elsewhere on the board
/CON1/-12V_PWR: J6.2; also elsewhere on the board
Earth: J6.8; also elsewhere on the board
GND: C44.2, C45.2, C46.2, C47.2, C48.2, C49.2, D10.2 (A), J6.6, J6.7, TP2.1 (1_1); also elsewhere on the board
unnamed: C47.1, C48.1, C49.1, D10.1 (K), F1.1, L1.2

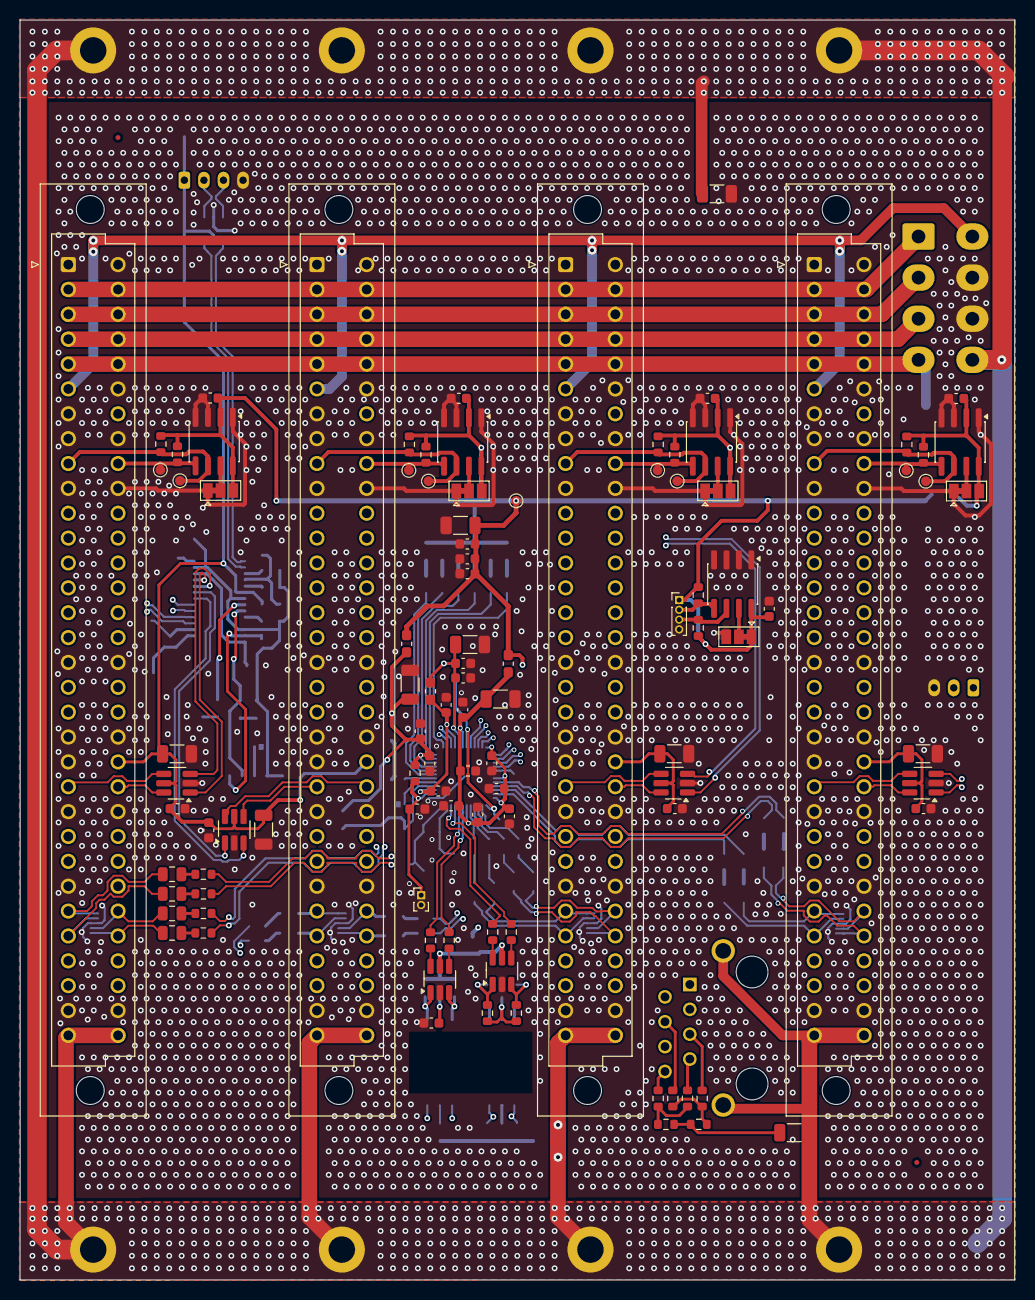
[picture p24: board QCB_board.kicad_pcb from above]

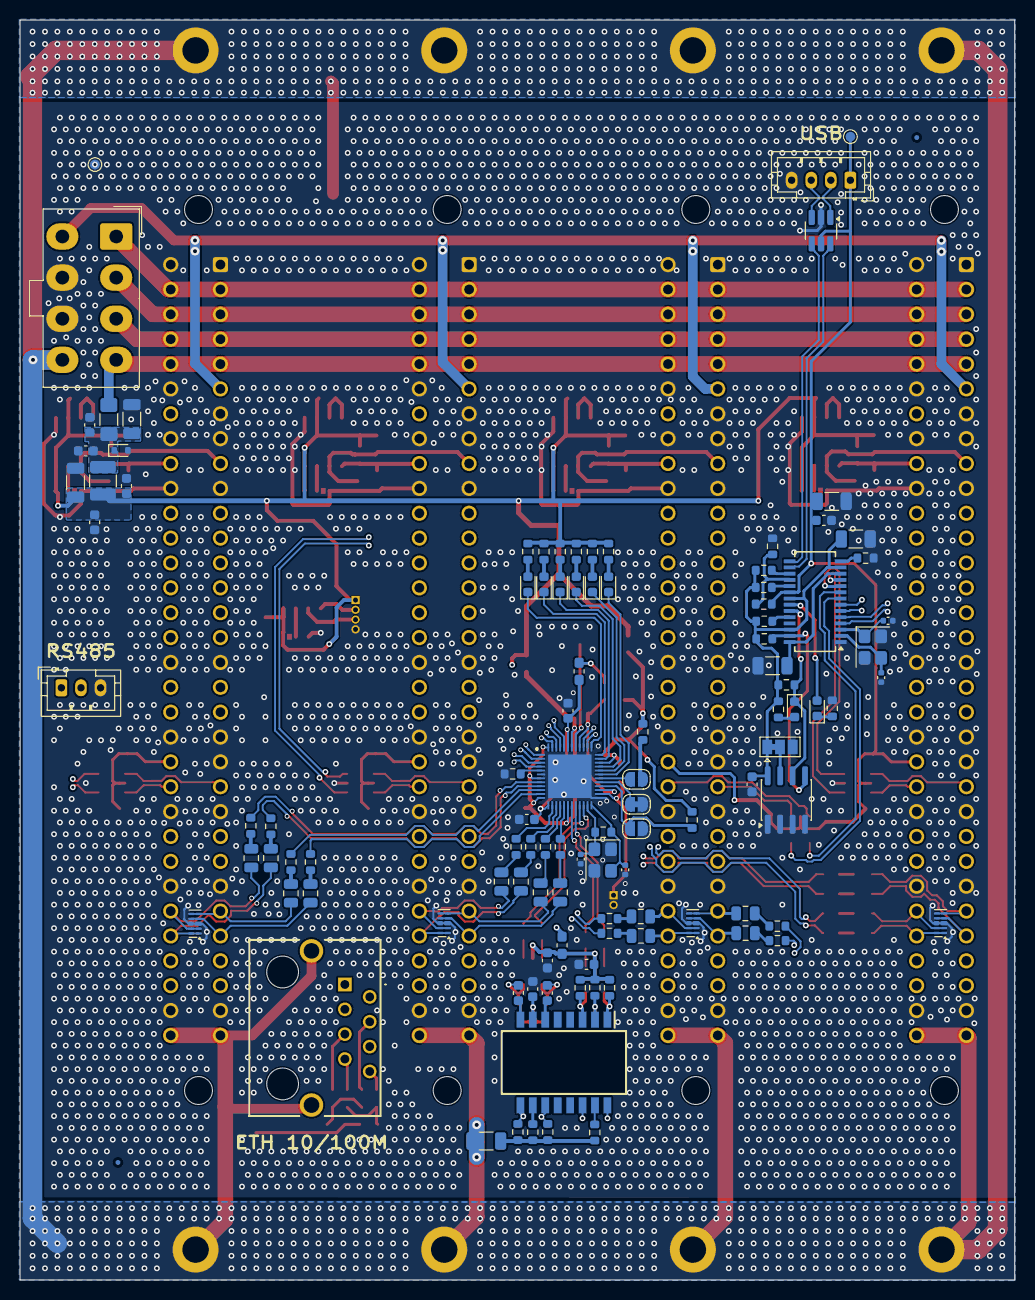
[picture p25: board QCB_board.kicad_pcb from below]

Board: 4 copper layers, 101.6 x 128.7 mm, 222 parts (110 on the bottom side), 166 nets.

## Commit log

2026-05-18 Schematic design
    [QCB_board.kicad_sch, con1.kicad_sch, pwr.kicad_sch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]
2026-05-18 More schematic
    [QCB_board.kicad_sch, eth_switch.kicad_sch, usb_switch.kicad_sch]
2026-05-19 Add symbols and adjust component positions in eth_switch schematic
    [eth_switch.kicad_sch]
2026-06-29 Sch complete, starting pcb
    [QCB_board.kicad_pcb, QCB_board.kicad_sch, con1.kicad_sch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]
2026-07-14 More routing
    [QCB_board.kicad_sch, backplane.dxf, backplane2.dxf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]
2026-08-03 Add design review docs, expand README, sync PCB routing and production outputs
    Routing progress on schematic/PCB, generated production outputs (gerbers,
    BOM, PDFs), 3D model cache, and datasheet sync. Adds doc/ (design review
    report + TODO) and README overview of architecture/status/repo layout.
    Analysis tool output moved to .gitignore (regenerable, not source).
    [QCB_board.csv, QCB_board.kicad_sch, con1.kicad_sch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]
2026-08-21 DNP update
    [QCB_board.csv, con1.kicad_sch]
2026-08-27 Unify passive values/footprints, add via-in-pad DRC rule, regen outputs
    [QCB_board.csv, QCB_board.kicad_pcb, eth_switch.kicad_sch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]
2026-09-25 Apply review checklist fixes, add fiducials, regenerate production outputs
    - C41/C42 (Y2 load caps) now included in BOM
    - Add USB hub crystal load caps C50/C51 (DNP), rework Y1 area placement
    - 2 fiducials per side (hand assembly)
    - Add IP175G, FE1.1s and UT8413A datasheets to doc/datasheet
    - README: status updated (ready for prototype order), production links
    - .gitignore: drop leftover SCA_board ibom.config.ini entry
    - Regenerate BOM, PDFs, gerber zip, interactive BOM and 3D renders
    [QCB_board.csv, QCB_board.kicad_pcb, QCB_board.kicad_sch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]
2026-09-28 Fix BOM data: LED part numbers (D1-D8), BOM field cleanup, BOM export settings
    [QCB_board.kicad_sch, con1.kicad_sch, eth_switch.kicad_sch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]
2026-09-28 Regenerate production outputs and gerber zip after BOM field fixes
    [QCB_board.csv]
2026-11-08 Order prep: project settings; regenerate gerber zip and PDFs
2026-11-08 BOM fields: MPN / Manufacturer / LCSC / TME / Mouser from Big_order_2026 rev.2 order (unified part numbers), old sourcing fields (Manufacturer_Part_Number, MF, MP, Mouser/Arrow/TME price fields, Snap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
2026-11-08 PCB updated from schematic (F8: MPN/LCSC/TME/Mouser fields); regenerate gerber zip, iBOM (MPN/LCSC/TME/Mouser columns), BOM and PDFs
